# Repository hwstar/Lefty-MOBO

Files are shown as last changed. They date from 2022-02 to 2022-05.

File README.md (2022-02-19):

# Lefty-MOBO
Lefty Double Conversion Transceiver Motherboard

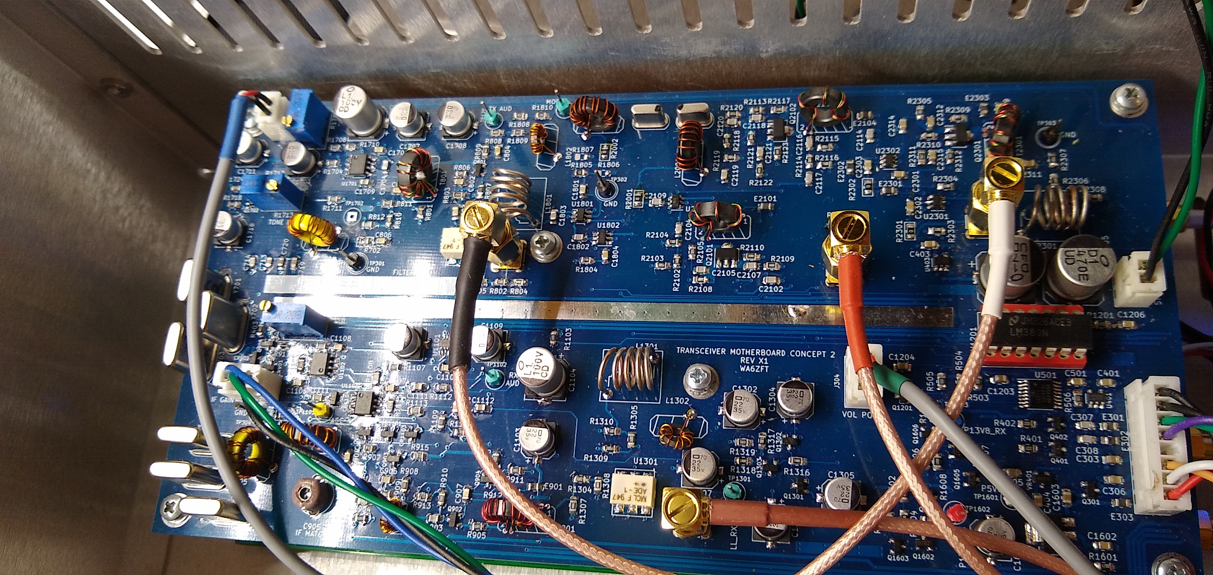
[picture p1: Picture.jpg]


This is an HF Motherboard consisting of the entire signal chain from RF in to Speaker, and from Microphone to RF out.  A double conversion topology was chosen to allow the motherboard to operate on all HF bands with minimal intermodulation products close to the operating frequency.

The design uses 5 AS169-73 Skyworks RF switches,  3 Mini Circuits ADE-1 mixers, a pair 45.1 MHz matched Golledge 15 KHz BW IF filters, 6 matched 12.288 MHz crystals for the second IF SSB filter, and 3 2SC3357 low noise RF transistors in the 45.1 MHz "transverter" section. The speaker amplifier is an LM380.

This design was inspired from W7ZOI's single conversion "Lichen" Transceiver originally published in EMRFD. I use the dual JFET IF amplifer, AGC circuit, 3 transistor post-detector audio amplifier, and TX speech amplifier from that design in this design.

Please note that this is not a complete Transceiver system. The transceiver board will additionally require a 3 output VFO (My implementation uses one SI5351, and may use 2 of them in the future so that I can drive all the Mixers at 8mA) ,  external bandpass filter bank, an RF power amplifier, and a TX low pass filter bank.

Mixer 1 (U801) serves as a downconverter in RX mode, and a balanced modulator TX mode. This converts the 45.1 MHz first IF to 12.288 MHz second IF. In TX mode, the VFO provides the carrier frequency (which depends on the characteristics of the crystal filter)

Mixer 2 (U1301) serves as the product detector in RX mode, and a 12.288 MHz upconverter in TX mode.

Mixer 3 (U2201) provides downconversion from the 45.1 MHz first IF to the desired HF band.

Mixer 1, The first IF amplifier, and Mixer 2 operate in the same direction for both TX and RX, but the mixers change function depending upon whether they're being used in TX or RX. A pair of AS169-73 RF switches, some RF chokes and RF traps are used to select the TX mode, and to filter out RF from getting into the audio stages.

The 45.1 MHz first IF uses the "BITx" concept with 2SC3357 bidirectional amplifiers i.e. left-to-right, and right-to-left controlled by a pair of AS169-73 RF switches, and the P13V8_RX and P13V8_TX power rails. The 2SC3357's are biased for 40mA operation.

After Mixer3 there is a stage of TX RF amplification using a 2SC3357 to bring up the signal level what is required for the RF power amplifier (not included on this board). This amplifier is bypassed in RX mode using a AS169-73.

All control to the Lefty Motherboard is done over I2C using an NXP PCA9554 at 7 bit address 0x38. This allows the wiring from the Motherboard to be minimal. 
The I2C interface allows control AS169-73 RF switches, PTT, Rx Audio Mute circuit, AGC on/off, and the TX tune audio oscillator. The SCL and SDA pins at the connector operate at 3.3V and are intended to be used with newer 3.3V microcontrollers available such as the STM32 "black pill".

There is an I2C EEPROM on the board to facilitate storing the TX gain values for each band, and crystal filter 6dB points and bandwidth, and a DAC which is used to control the 12.288 MHz IF amplifier's gain in TX to help flatten out the TX power across all bands. TX gain may also be set manually by removing the DAC and and installing a 20K pot at R918. 

The PCB design was done with KiCAD 5.0. The BOM files are in .csv format and are included in the top level directory. There is a combined BOM, separate top and bottom SMT BOM's, and a PTH BOM.

The gerber files are in the directory TRX_MB_C2_X1

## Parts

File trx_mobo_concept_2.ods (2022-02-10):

Item | Part Number | Qty | Reference(s) | Title/Description | Value on Schematic | Manufacturer | Manufacturer Part Number
1 | 800238-104 | 48 | C301,C302,C305,C309,C310,C401-C403,C501,C801-C806,C901,C902,C906-C910,C1101,C1105-C1108,C1201,C1206,C1303,C1602,C1701,C1705,C1706,C1710,C1801,C1802,C1804,C2301-C2304,C2309-C2312,C2314,C2315 | CAP,0805,0.1u,50V,X7R | 0.1u | Open Market | N/A
2 | 800267-226 | 14 | C1102,C1103,C1109,C1302,C1304-C1307,C1601,C1703,C1707,C1708,C1711,C1716 | CAP,ALUM ELECT,GP,22UF,25V,SMD,CS=6.3MM | 22u | Open Market | N/A
3 | 800268-107 | 2 | C1104,C1702 | CAP,ALUM,ELECT,GP,100UF,35V,SMD,CS=8MM | 100u | Open Market | N/A
4 | 800238-105 | 2 | C404,C1110 | CAP,0805,1u,50V,X7R | 1u | Open Market | N/A
5 | 800003-475 | 5 | C1111,C1112,C1203,C1204,C1603 | CAP,0805,4.7u,25V,X5R | 4.7u | Open Market | N/A
6 | 800270-477 | 2 | C1202,C1205 | CAP,ALUM,ELECT,GP,470UF,25V,SMD,CS=10MM | 470u | Open Market | N/A
7 | 800232-151 | 3 | C1301,C1805,C2313 | CAP,0805,C0G,150PF,250V | 150p | Open Market | N/A
8 | 800239-103 | 1 | C1704 | CAP,0805,C0G/NPO,10000PF,50V | 0.01u | Open Market | N/A
9 | 800239-272 | 5 | C1709,C1712-C1715 | CAP,0805,C0G/NPO,2700PF,50V | 0.0027u | Open Market | N/A
10 | 800238-103 | 21 | C903,C904,C1717,C1803,C2101-C2109,C2114-C2121 | CAP,0805,0.01u,50V,X7R | 0.01u | Open Market | N/A
11 | 800239-160 | 2 | C2001,C2003 | CAP,0805,C0G/NPO,16PF,50V | 16p | Open Market | N/A
12 | 800239-082 | 1 | C2002 | CAP,0805,C0G/NPO,8.2PF,50V | 8.2p | Open Market | N/A
13 | 800238-102 | 8 | C2110-C2113,C2305-C2308 | CAP,0805,1000p,50V,X7R | 1000p | Open Market | N/A
14 | 800003-106 | 3 | C303,C306,C405 | CAP,0805,10u,25V,X5R | 10u | Open Market | N/A
15 | 800239-102 | 1 | C304 | CAP,0805,C0G/NPO,1000PF,50V | 1000p | Open Market | N/A
16 | 800239-101 | 2 | C307,C308 | CAP,0805,C0G/NPO,100PF,50V | 100p | Open Market | N/A
17 | 800239-431 | 2 | C701,C702 | CAP,0805,C0G/NPO,430PF,50V | 430p | Open Market | N/A
18 | 800239-150 | 2 | C703,C704 | CAP,0805,C0G/NPO,15PF,50V | 15p | Open Market | N/A
19 | 800239-121 | 2 | C705,C710 | CAP,0805,C0G/NPO,120PF,50V | 120p | Open Market | N/A
20 | 800239-151 | 7 | C706,C709,C712,C713,C716,C717,C719 | CAP,0805,C0G/NPO,150PF,50V | 150p | Open Market | N/A
21 | 800239-100 | 4 | C707,C708,C714,C715 | CAP,0805,C0G/NPO,10PF,50V | 10p | Open Market | N/A
22 | 800239-180 | 1 | C711 | CAP,0805,C0G/NPO,18PF,50V | 18p | Open Market | N/A
23 | 800239-200 | 2 | C718,C720 | CAP,0805,C0G/NPO,20PF,50V | 20p | Open Market | N/A
24 | 800241-600 | 1 | C905 | CAP,TRIMMER,PLASTIC,PTH,6MM,60PF | 60p | Open Market | N/A
25 | 800127-101 | 6 | CR901,CR902,CR1101-CR1104 | DIODE,SCHOTTKY,SGL,SOT-23 | BAT54 | Diodes Inc. | BAT54-7-F
26 | 800245-601 | 11 | E301-E303,E901,E2101-E2104,E2301-E2303 | FERRITE,CHIP,0805,600 ohm,100MHz,500mA | GZ2012U601TF | Sunlord | GZ2012U601TF
27 | 800253-101 | 4 | J301,J303,J305,J308 | CONN, SMA, VERTICAL, PCB MOUNT | CONN_SMA_VERT | Kinghelm | KH-SMA-KE-Z
28 | 800114-102 | 2 | J302,J307 | CONN,HDR,SHROUDED,2 CKT,5MM,XH SERIES | CONN2 | JST | B2B-XH-A
29 | 800114-103 | 2 | J304,J306 | CONN,HDR,SHROUDED,3 CKT,5MM,XH SERIES | CONN3 | JST | B3B-XH-A
30 | 800114-108 | 1 | J309 | CONN,HDR,SHROUDED,8 CKT,5MM,XH SERIES | CONN8 | JST | B8B-XH-A
31 | 800YYY-YYY | 3 | L1301,L1801,L2301 | Unknown | 81nH | Unknown | Unknown
32 | 800257-023 | 3 | L901,L1302,L1802 | FERRITE,TOROID,OD 5.95MM,TYPE 43 | 27uH | Open Market | FT23-43
33 | 800234-370 | 2 | L2001,L2002 | TOROID,POWDERED_IRON,T37-10 | 0.563uH | Open Market | N/A
34 | 800234-376 | 2 | L701,L702 | TOROID,POWDERED_IRON,T37-6 | 0.97uH | Open Market | N/A
35 | 800276-037 | 1 | L902 | FERRITE,TOROID,OD 9.5MM,TYPE 61 | 4.13uH | Open Market | FT37-61
36 | 800236-101 | 7 | Q301,Q401,Q402,Q905,Q1201,Q1602,Q1605 | XSTR,SOT-23,MOSFET,N-CH,50V | BSS138 | Open Market | BSS138
37 | 800259-101 | 10 | Q801,Q903,Q904,Q1301-Q1303,Q1603,Q1606,Q1702,Q1703 | XSTR,GP,NPN,SOT-23,FT=300MHz | MMBT3904 | Open Market | MMBT3904
38 | 800134-101 | 2 | Q1601,Q1604 | XSTR,MOSFET,P-CH,SOT-23,30V,-7.6A | SI2369 | Vishay | SI2369DS-T1-E3
39 | 800275-101 | 1 | Q1701 | XSTR,PNP,GP,FT=300MHZ,SOT-23 | MMBT3906 | Open Market | MMBT3906
40 | 800246-101 | 3 | Q2101,Q2102,Q2301 | XSTR,BJT,NPN,RF,SOT89,1.2W | 2SC3357 | Open Market | 2SC3357
41 | 800263-101 | 2 | Q901,Q902 | XSTR,RF,J-FET,N-CH,DEPLETION MODE | MMBFJ310 | Open Market | MMBFJ310
42 | 800235-103 | 25 | R301,R401,R402,R501,R502,R915,R916,R1101,R1102,R1106,R1107,R1110,R1111,R1113,R1315,R1602,R1605,R1606,R1609,R1702-R1704,R1706,R1707,R1724 | RES,0805,10K,1% | 10K | Open Market | N/A
43 | 800235-101 | 7 | R403,R1103,R1318,R1604,R1608,R1701,R1718 | RES,0805,100,1% | 100 | Open Market | N/A
44 | 800235-104 | 3 | R1104,R1108,R1711 | RES,0805,100K,1% | 100K | Open Market | N/A
45 | 800235-225 | 1 | R1105 | RES,0805,2.2M,1% | 2.2M | Open Market | N/A
46 | 800235-102 | 10 | R503-R506,R1109,R1312,R1314,R1712,R1808,R1810 | RES,0805,1.0K,1% | 1K | Open Market | N/A
47 | 800235-471 | 2 | R1112,R1601 | RES,0805,470,1% | 470 | Open Market | N/A
48 | 800235-473 | 9 | R1114,R1311,R1714,R1717,R1719-R1722,R1725 | RES,0805,47K,1% | 47K | Open Market | N/A
49 | 800235-027 | 1 | R1201 | RES,0805,2.7,1% | 2.7 | Open Market | N/A
50 | 800235-180 | 6 | R802,R1301,R1304,R1801,R1805,R2201 | RES,0805,18,1% | 18 | Open Market | N/A
51 | 800235-301 | 8 | R804,R805,R1302,R1303,R1307,R1308,R2202,R2203 | RES,0805,300,1% | 300 | Open Market | N/A
52 | 800235-360 | 6 | R810,R1305,R2102,R2114,R2118,R2306 | RES,0805,36,1% | 36 | Open Market | N/A
53 | 800235-000 | 10 | R701,R702,R917,R1306,R2001,R2002,R2106,R2107,R2301,R2302 | RES,0805,0,1% | 0 | Open Market | N/A
54 | 800235-151 | 12 | R811,R812,R1309,R1310,R2103,R2104,R2115,R2116,R2119,R2120,R2307,R2308 | RES,0805,150,1% | 150 | Open Market | N/A
55 | 800235-332 | 2 | R1313,R1317 | RES,0805,3.3K,1% | 3.3K | Open Market | N/A
56 | 800235-682 | 1 | R1316 | RES,0805,6.8K,1% | 6.8K | Open Market | N/A
57 | 800235-472 | 1 | R1319 | RES,0805,4.7K,1% | 4.7K | Open Market | N/A
58 | 800235-100 | 3 | R801,R1603,R1607 | RES,0805,10,1% | 10 | Open Market | N/A
59 | 800249-203 | 3 | R918,R1705,R1713 | RES,TRIMMER,3296,VERT,20K,10%,0.5W | 20K | Open Market | N/A
60 | 800235-681 | 1 | R1708 | RES,0805,680,1% | 680 | Open Market | N/A
61 | 800235-202 | 4 | R1709,R2101,R2113,R2305 | RES,0805,2.0K,1% | 2K | Open Market | N/A
62 | 800235-274 | 3 | R913,R914,R1710 | RES,0805,270K,1% | 270K | Open Market | N/A
63 | 800235-753 | 1 | R1715 | RES,0805,75K,1% | 75K | Open Market | N/A
64 | 800235-223 | 1 | R1716 | RES,0805,22K,1% | 22K | Open Market | N/A
65 | 800235-393 | 5 | R907,R908,R910,R911,R1723 | RES,0805,39K,1% | 39K | Open Market | N/A
66 | 800XXX-XXX | 4 | R1802,R1803,R1806,R1807 | Unknown | DNI | Unknown | Unknown
67 | 800235-510 | 2 | R1804,R1809 | RES,0805,51,1% | 51 | Open Market | N/A
68 | 800235-162 | 4 | R806,R2105,R2117,R2309 | RES,0805,1.6K,1% | 1.6K | Open Market | N/A
69 | 800235-361 | 3 | R2108,R2121,R2310 | RES,0805,360,1% | 360 | Open Market | N/A
70 | 800235-068 | 4 | R808,R2109,R2122,R2311 | RES,0805,6.8,1% | 6.8 | Open Market | N/A
71 | 800235-300 | 4 | R809,R2110,R2123,R2312 | RES,0805,30,1% | 30 | Open Market | N/A
72 | 800235-330 | 4 | R2111,R2112,R2303,R2304 | RES,0805,33,1% | 33 | Open Market | N/A
73 | 800235-392 | 1 | R803 | RES,0805,3.9K,1% | 3.9K | Open Market | N/A
74 | 800235-751 | 1 | R807 | RES,0805,750,1% | 750 | Open Market | N/A
75 | 800235-820 | 4 | R901,R902,R904,R905 | RES,0805,82,1% | 82 | Open Market | N/A
76 | 800235-222 | 2 | R903,R906 | RES,0805,2.2K,1% | 2.2K | Open Market | N/A
77 | 800235-391 | 2 | R909,R912 | RES,0805,390,1% | 390 | Open Market | N/A
78 | 800257-037 | 5 | T801,T901,T2101,T2102,T2301 | FERRITE,TOROID,OD 9.5MM,TYPE 43 | FT37-43 | Open Market | FT37-43
79 | 800207-101 | 13 | TP301-TP304,TP1101,TP1102,TP1301,TP1601-TP1603,TP1701,TP1702,TP1801 | TEST POINT, SGL,0.025 IN., SQ, PTH | TESTPINTPSQ025 | Open Market | N/A
80 | 800271-101 | 1 | U1101 | IC,SWITCH,ANALOG,HV,SPDT,SOT23-8 | DG449DS-T1-E3 | Vishay | DG449DS-E1-T3
81 | 800272-101 | 3 | U1102,U1103,U1701 | IC,OP-AMP,DUAL,RRIO,1.3MHZ,GBW,SOIC8 | LMC6482 | Texas Instruments | LMC6482AIM/NOPB
82 | 800269-101 | 1 | U1201 | IC,AUDIO AMPLIFIER,2.5W,DIP14 | LM380N | Texas Instruments | LM380N/NOPB
83 | 800262-101 | 3 | U801,U1301,U2201 | MODULE,MIXER,SMD,LEVEL 7,0.5 TO 500 MHZ | ADE-1 | Mini Circuits | ADE-1
84 | 800261-101 | 6 | U1801,U1802,U2101,U2102,U2301,U2302 | IC,RF SWITCH,SPDT,50 OHM | AS169-73 | Skyworks | AS169-73
85 | 800284-101 | 1 | U401 | IC,EEPROM,64KBIT,I2C,1.6-5.5V,SOT23-5 | 24CW640 | Microchip | 24CW640T-I/OT
86 | 800285-101 | 1 | U402 | IC,DAC,12 BIT,I2C,2.7-5.5V,SOT23-6 | MCP4725 | Microchip | MCP4725A1T-E/CH
87 | 800278-102 | 1 | U403 | IC,NAND GATE,2 INPUT,LVC,SOT23 | 74LVC1G00 | Texas Instruments | SN74LVC1G00DBVRG4
88 | 800237-101 | 1 | U501 | IC, I2C BUS EXPANDER, 8 BIT, TSSOP16 | PCA9554APW | NEXPERIA | PCA9554APW
89 | 800121-102 | 1 | VR1601 | IC,VREG,5V,1A,SOT-223 | NCP1117-5.0_SOT223 | On Semiconductor | NCP1117ST50
90 | 800187-101 | 1 | VR401 | IC,VREG,LDO,500MA,3.3V,SOT23 | ME6211A33M3G-N | Nanjing Micro One Elec | ME6211A33M3B-N
91 | 800287-101 | 2 | Y2001,Y2002 | FILTER,XTAL,MONOLITHIC,45.1 MHZ,15KHZ BW | 45.1 MHz | GOLLEDGE | GMCF-45T152AF
92 | 800286-101 | 6 | Y701-Y706 | CRYSTAL,HC-49U,12.288 MHZ,32PF | 12.288 MHz | CTS Crystals | MP122-E

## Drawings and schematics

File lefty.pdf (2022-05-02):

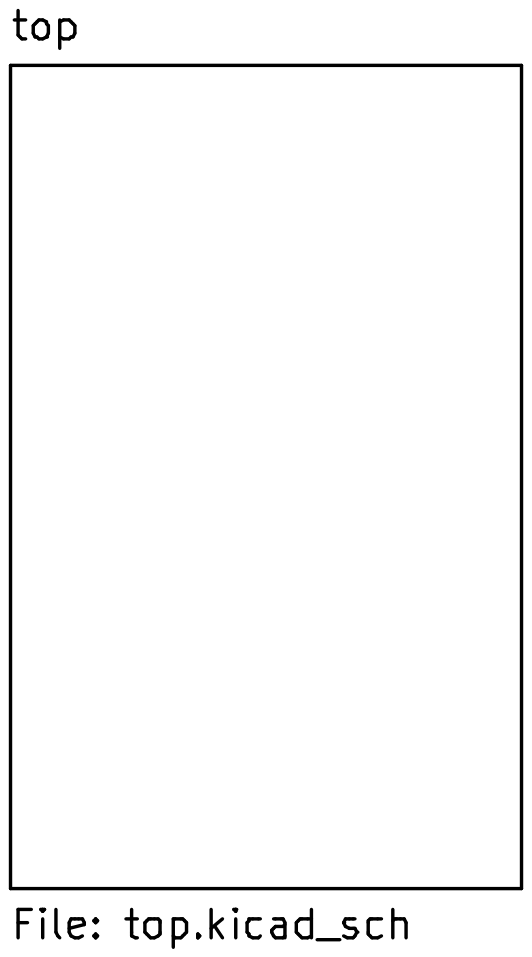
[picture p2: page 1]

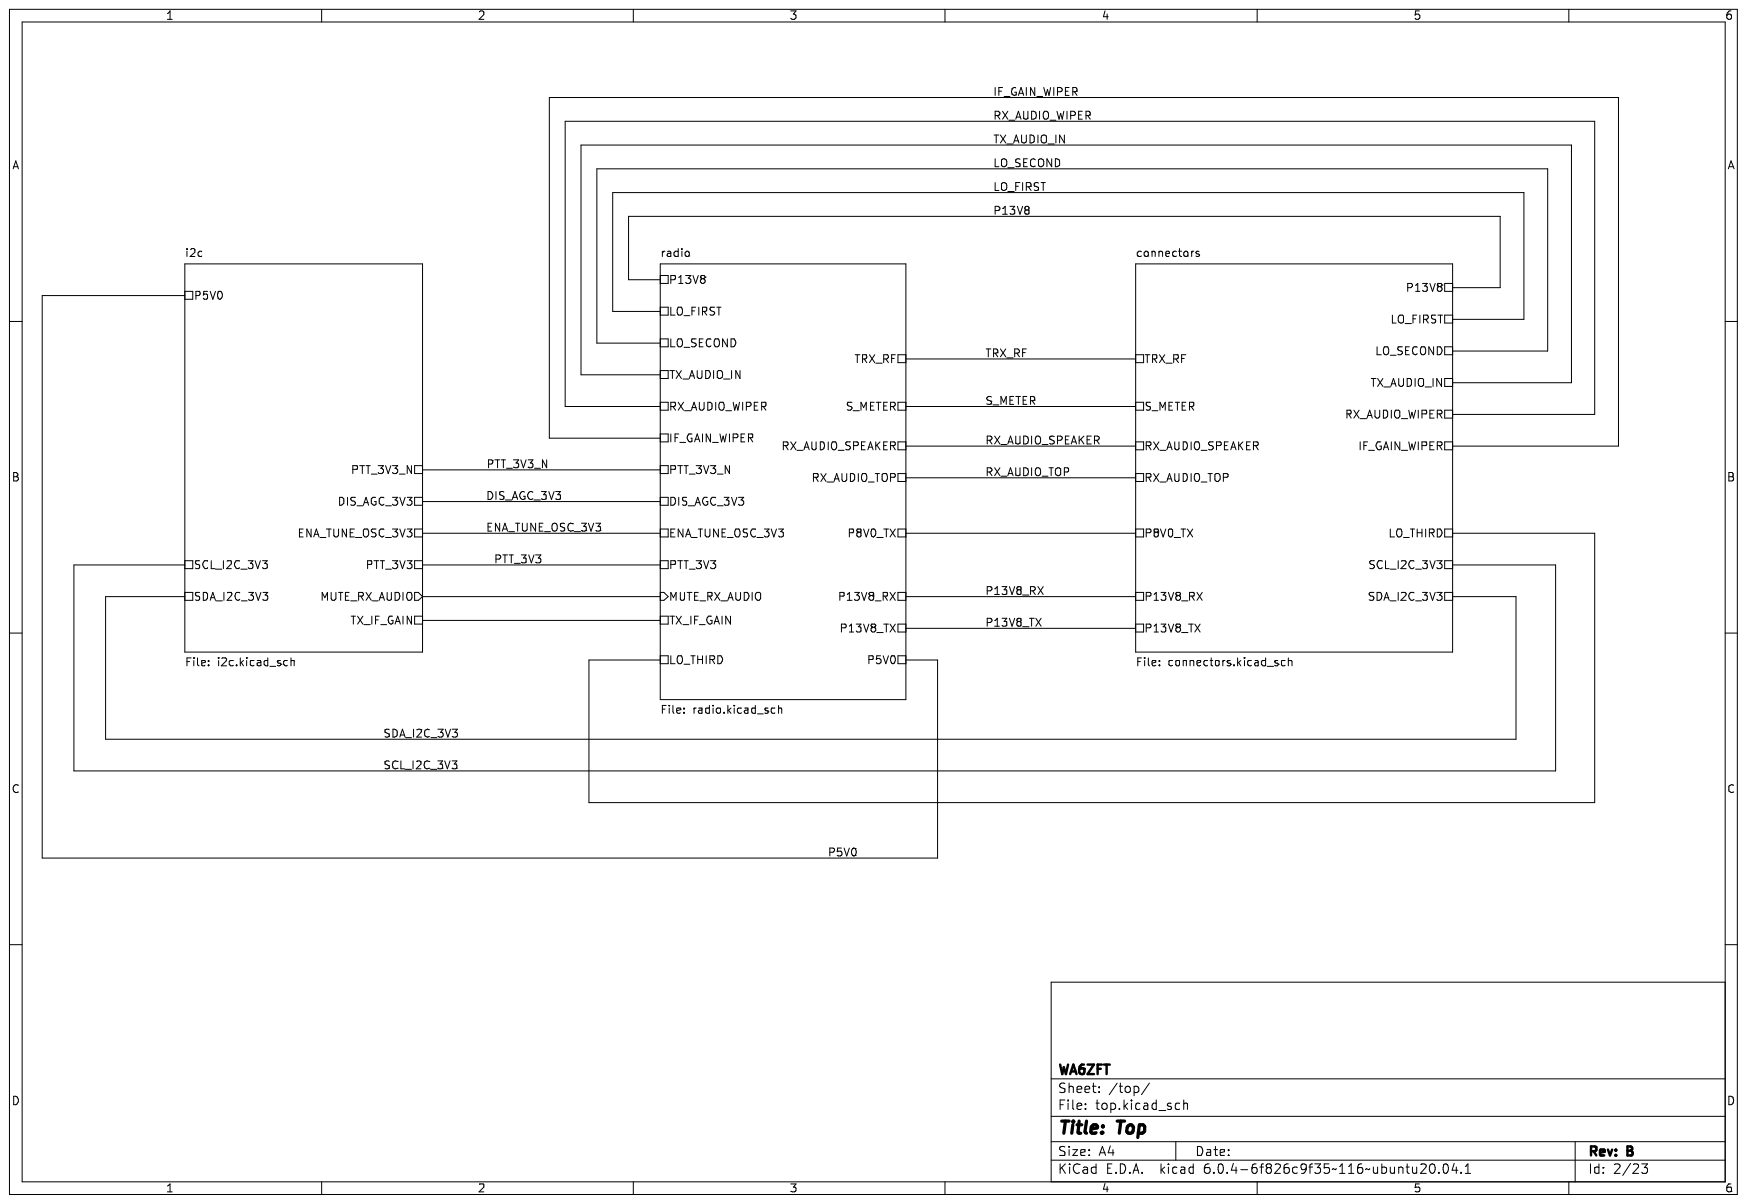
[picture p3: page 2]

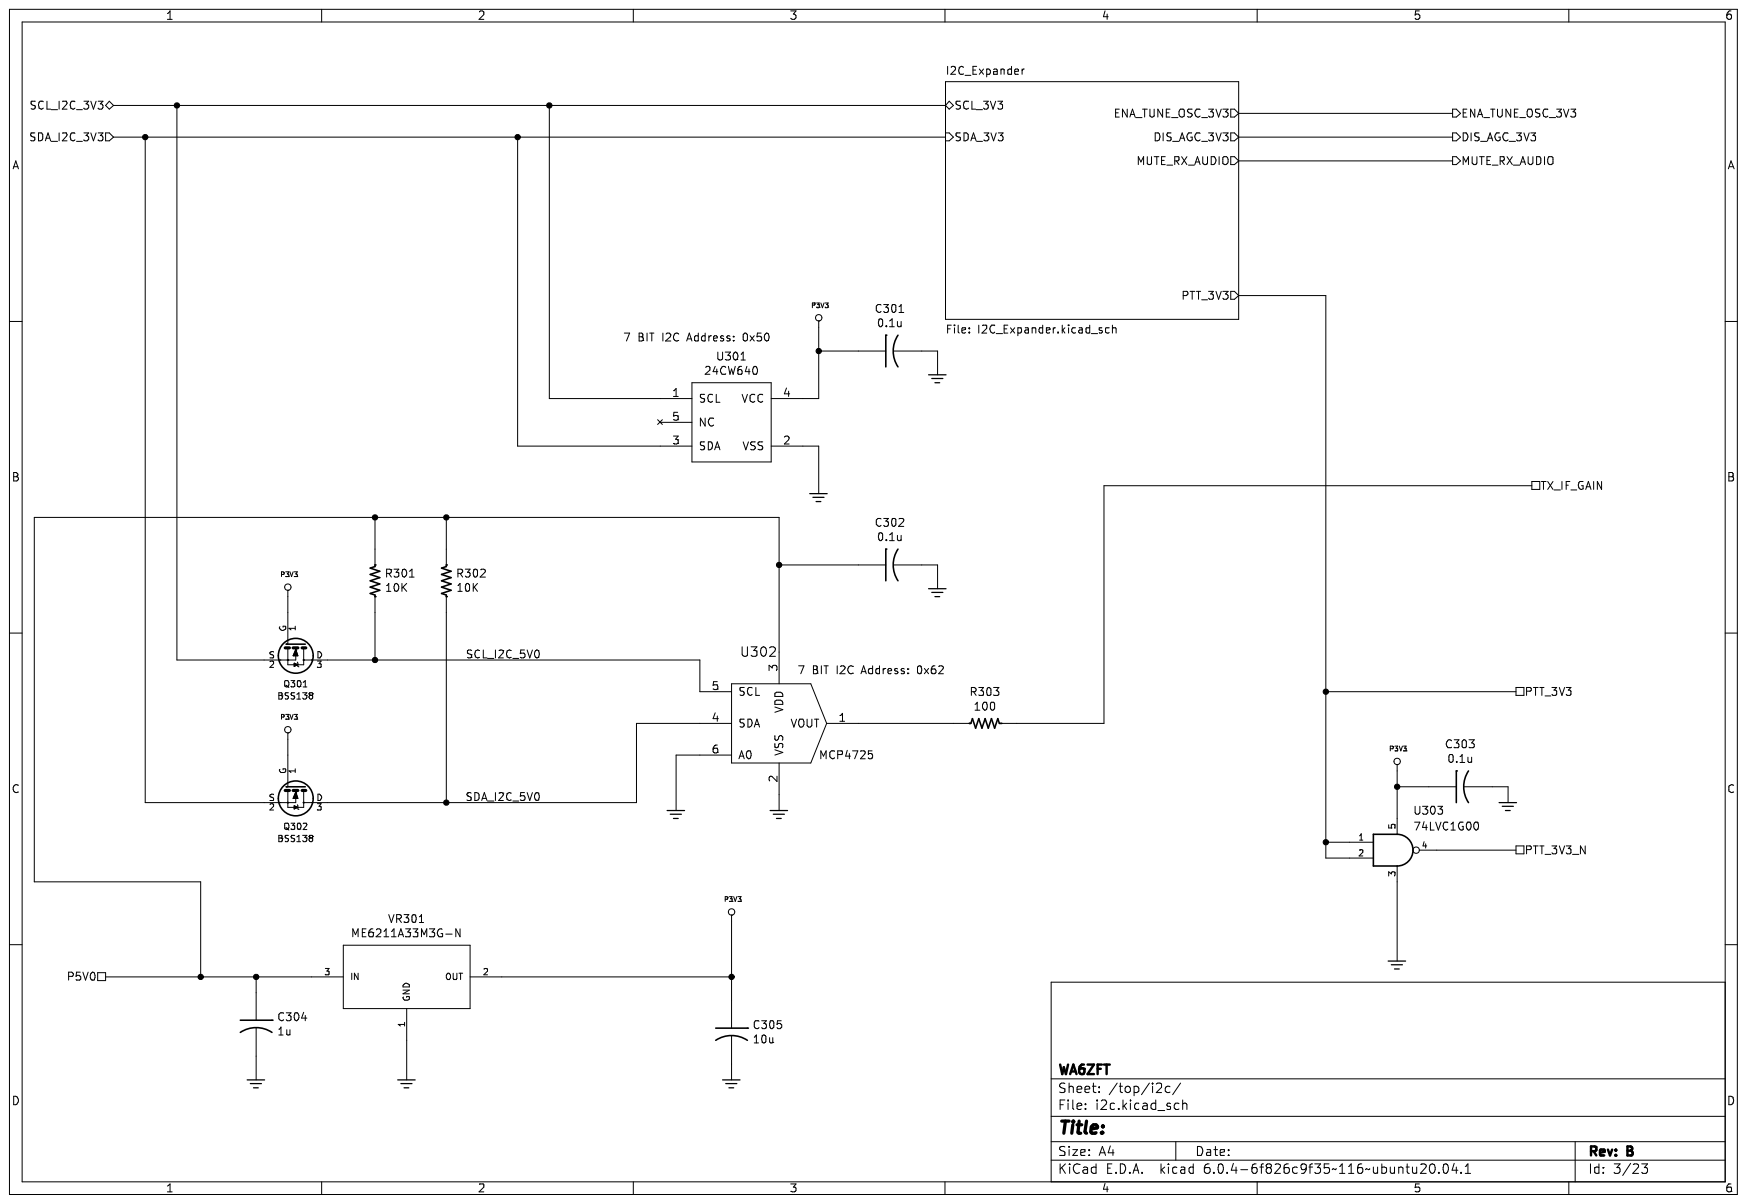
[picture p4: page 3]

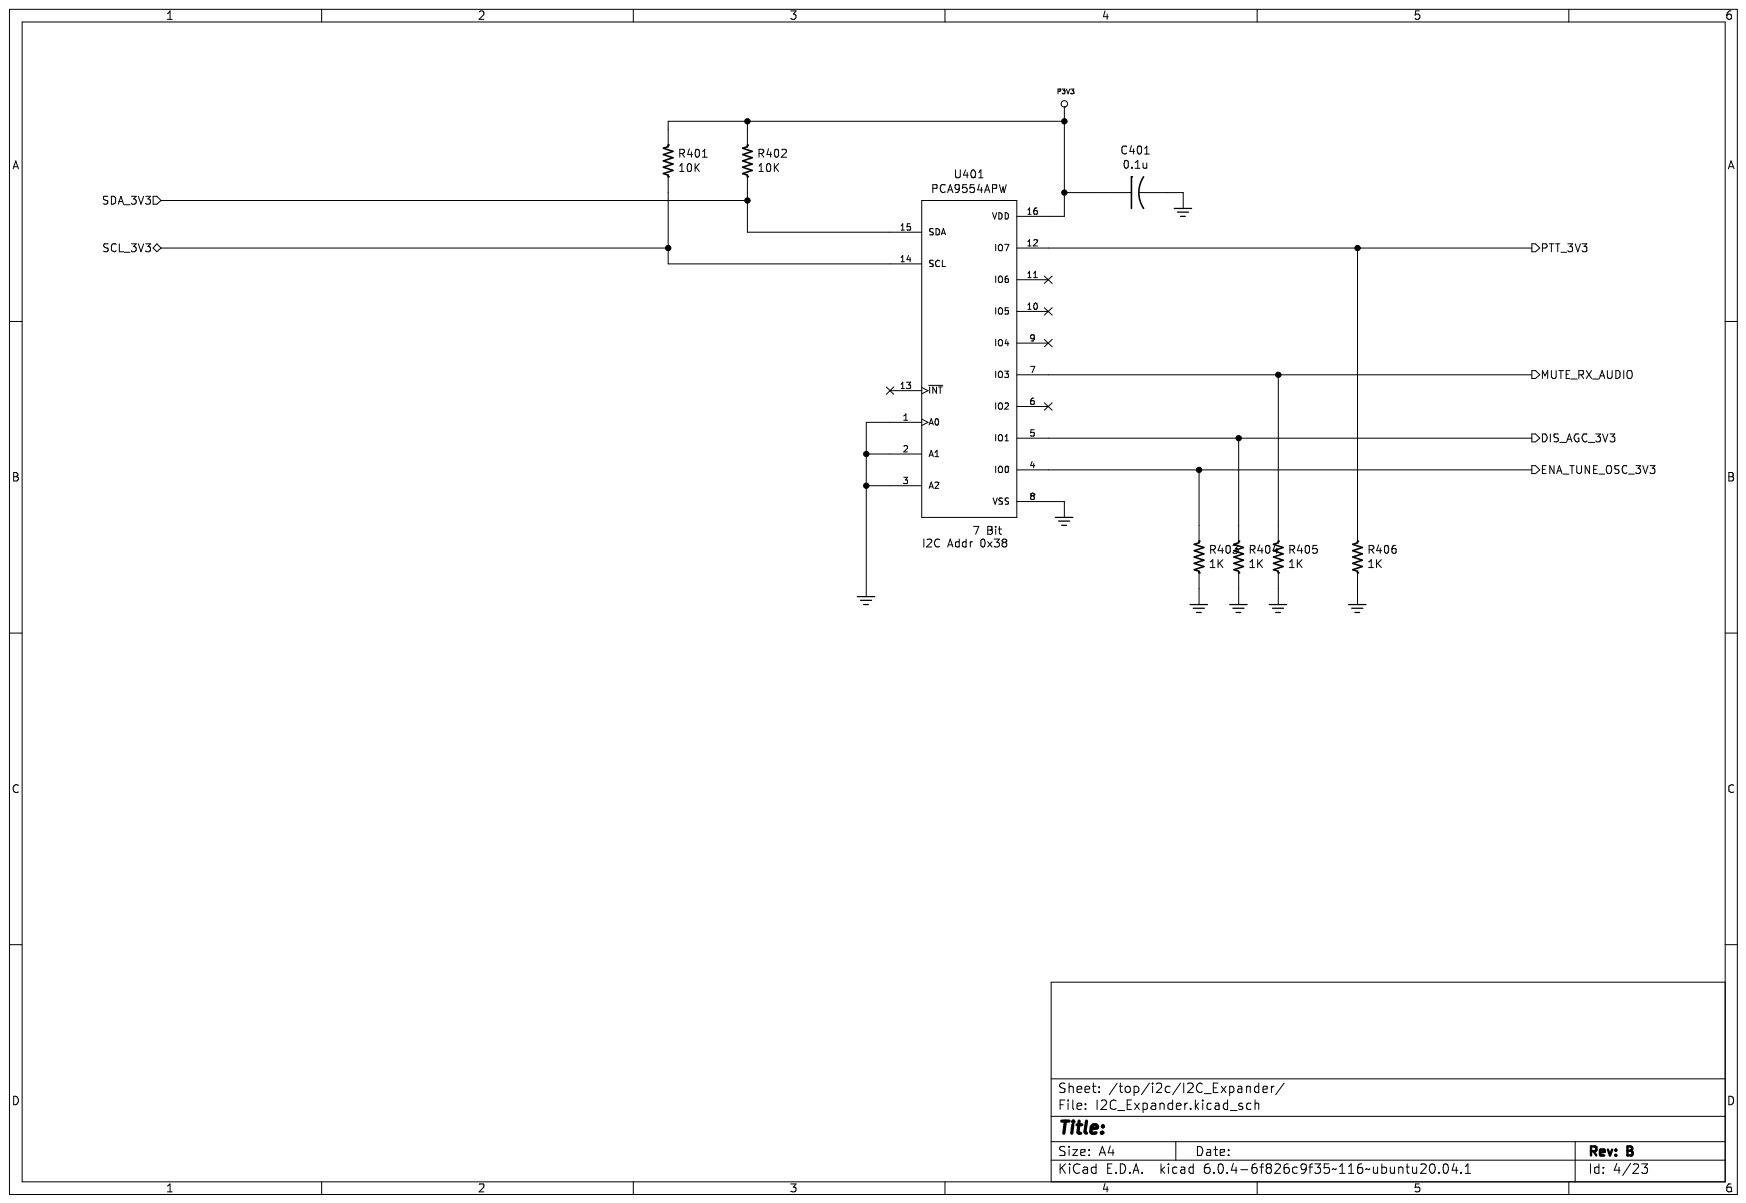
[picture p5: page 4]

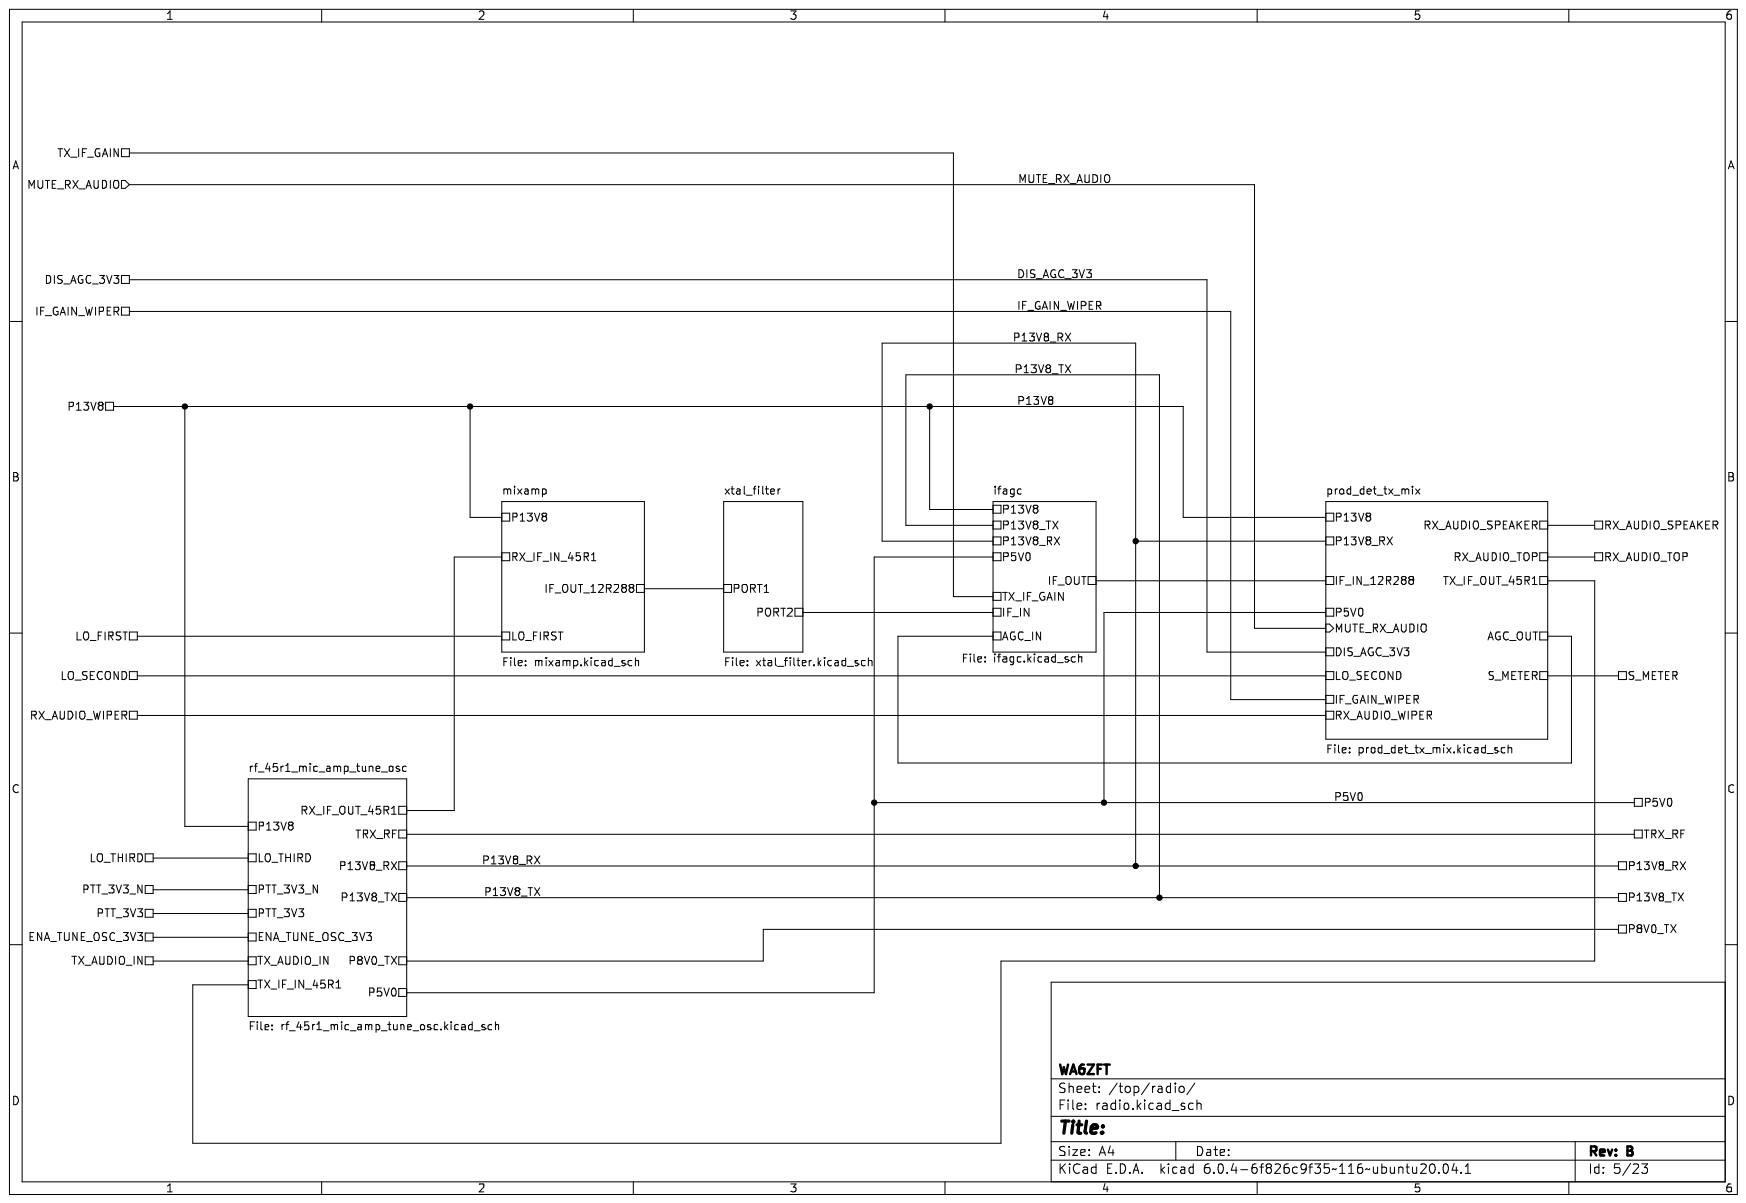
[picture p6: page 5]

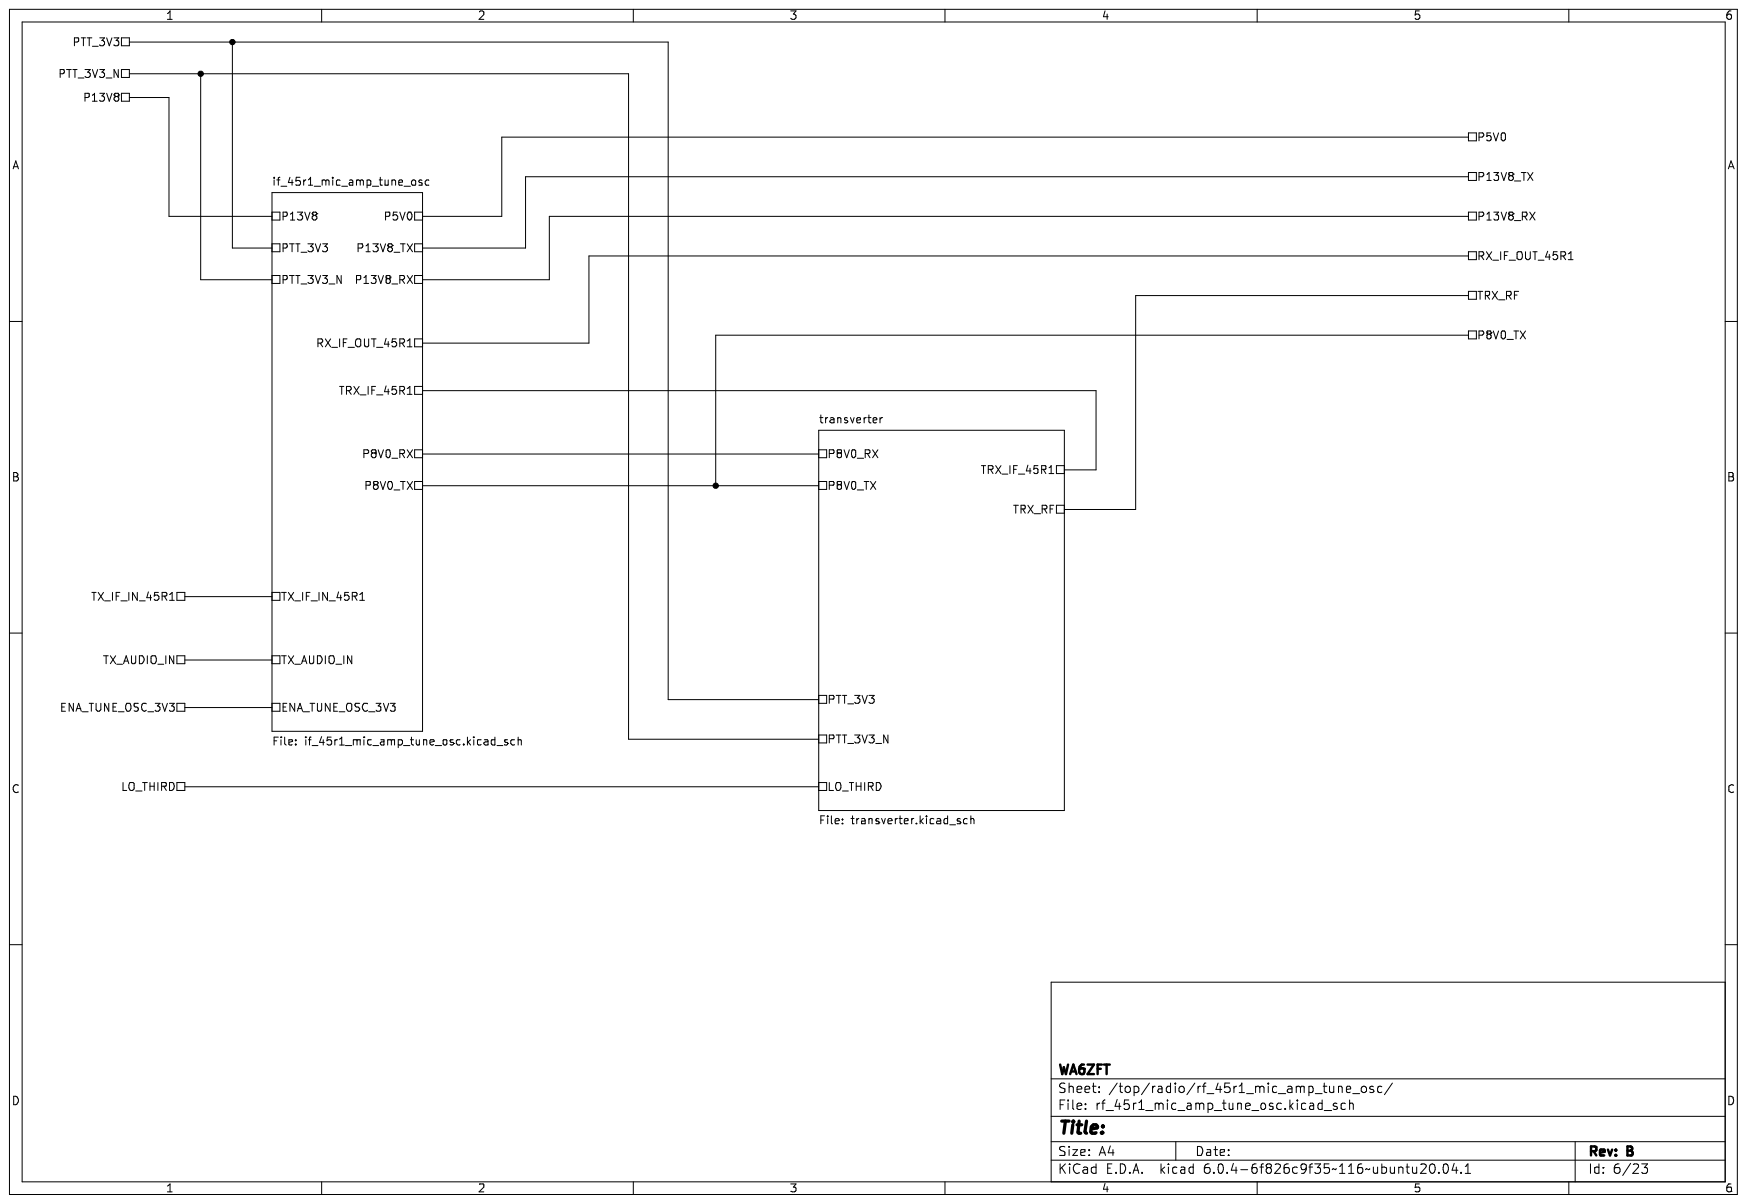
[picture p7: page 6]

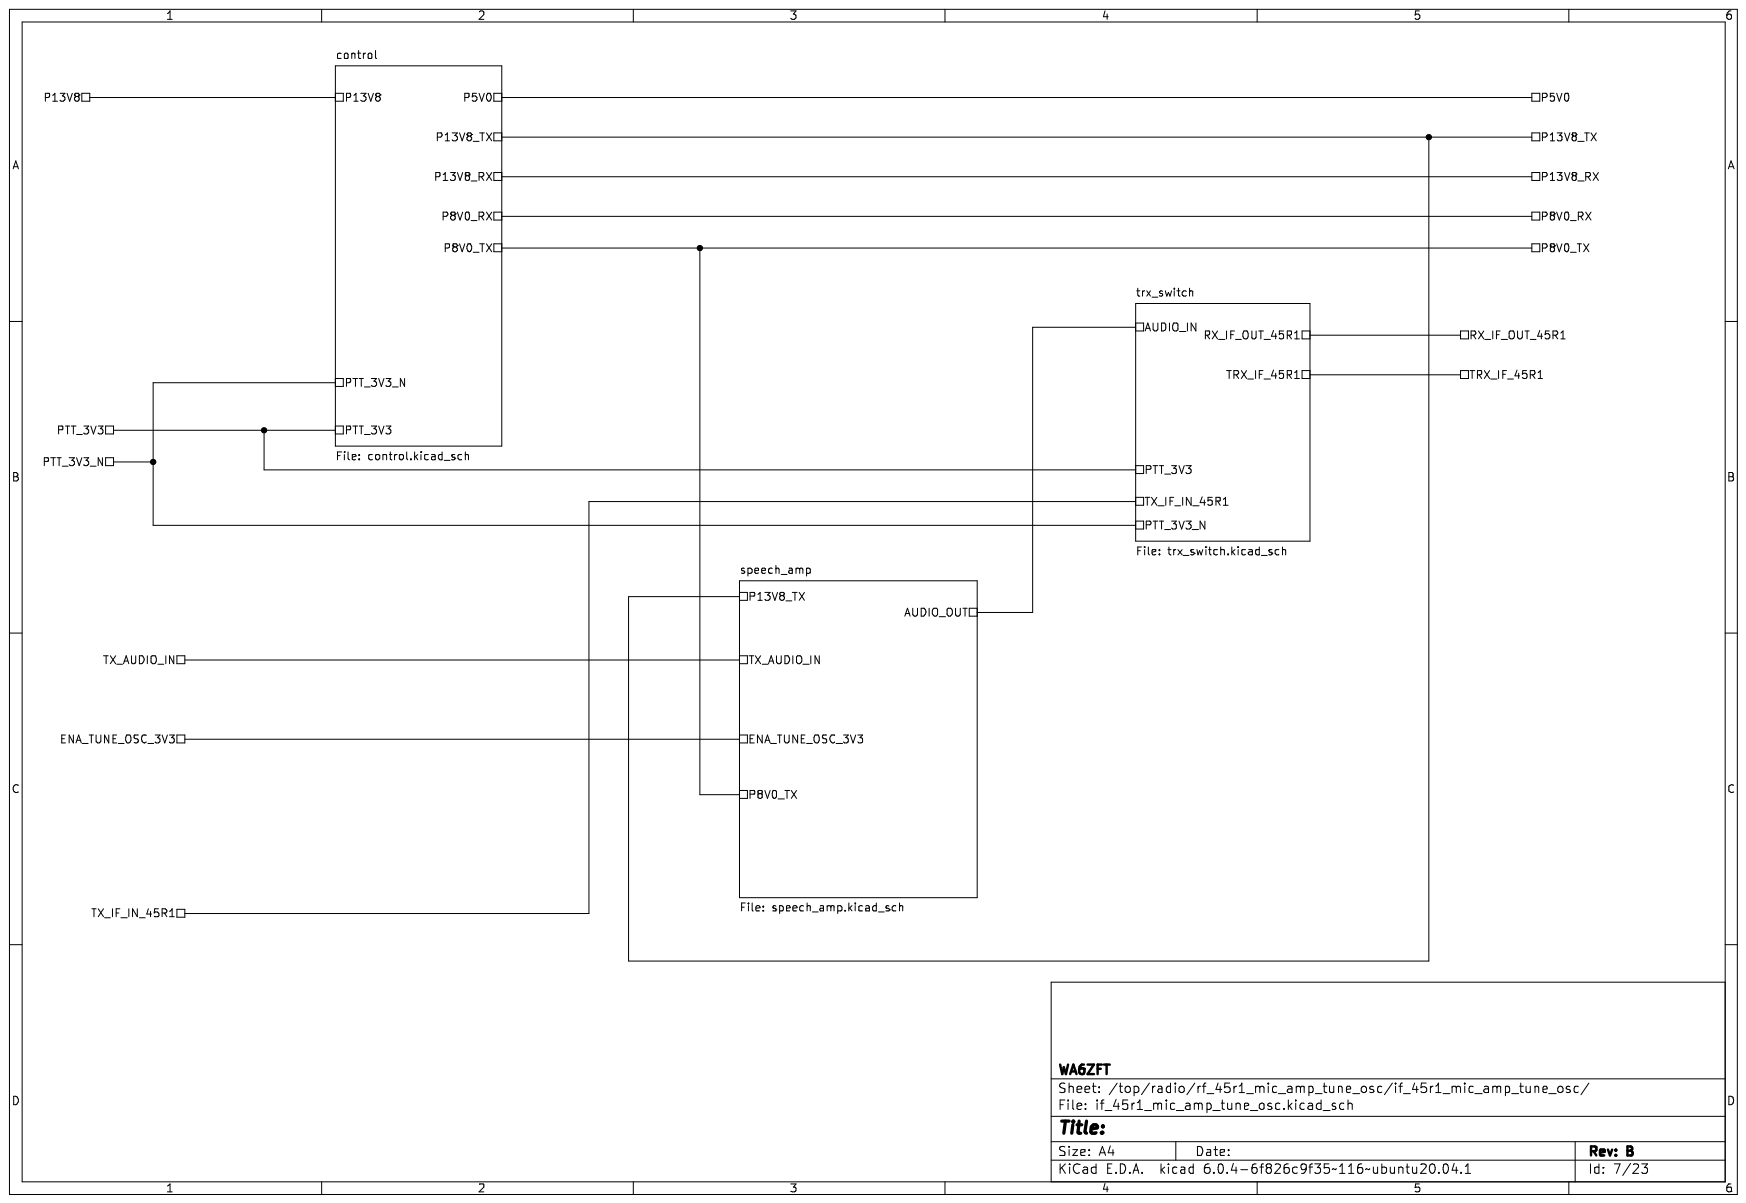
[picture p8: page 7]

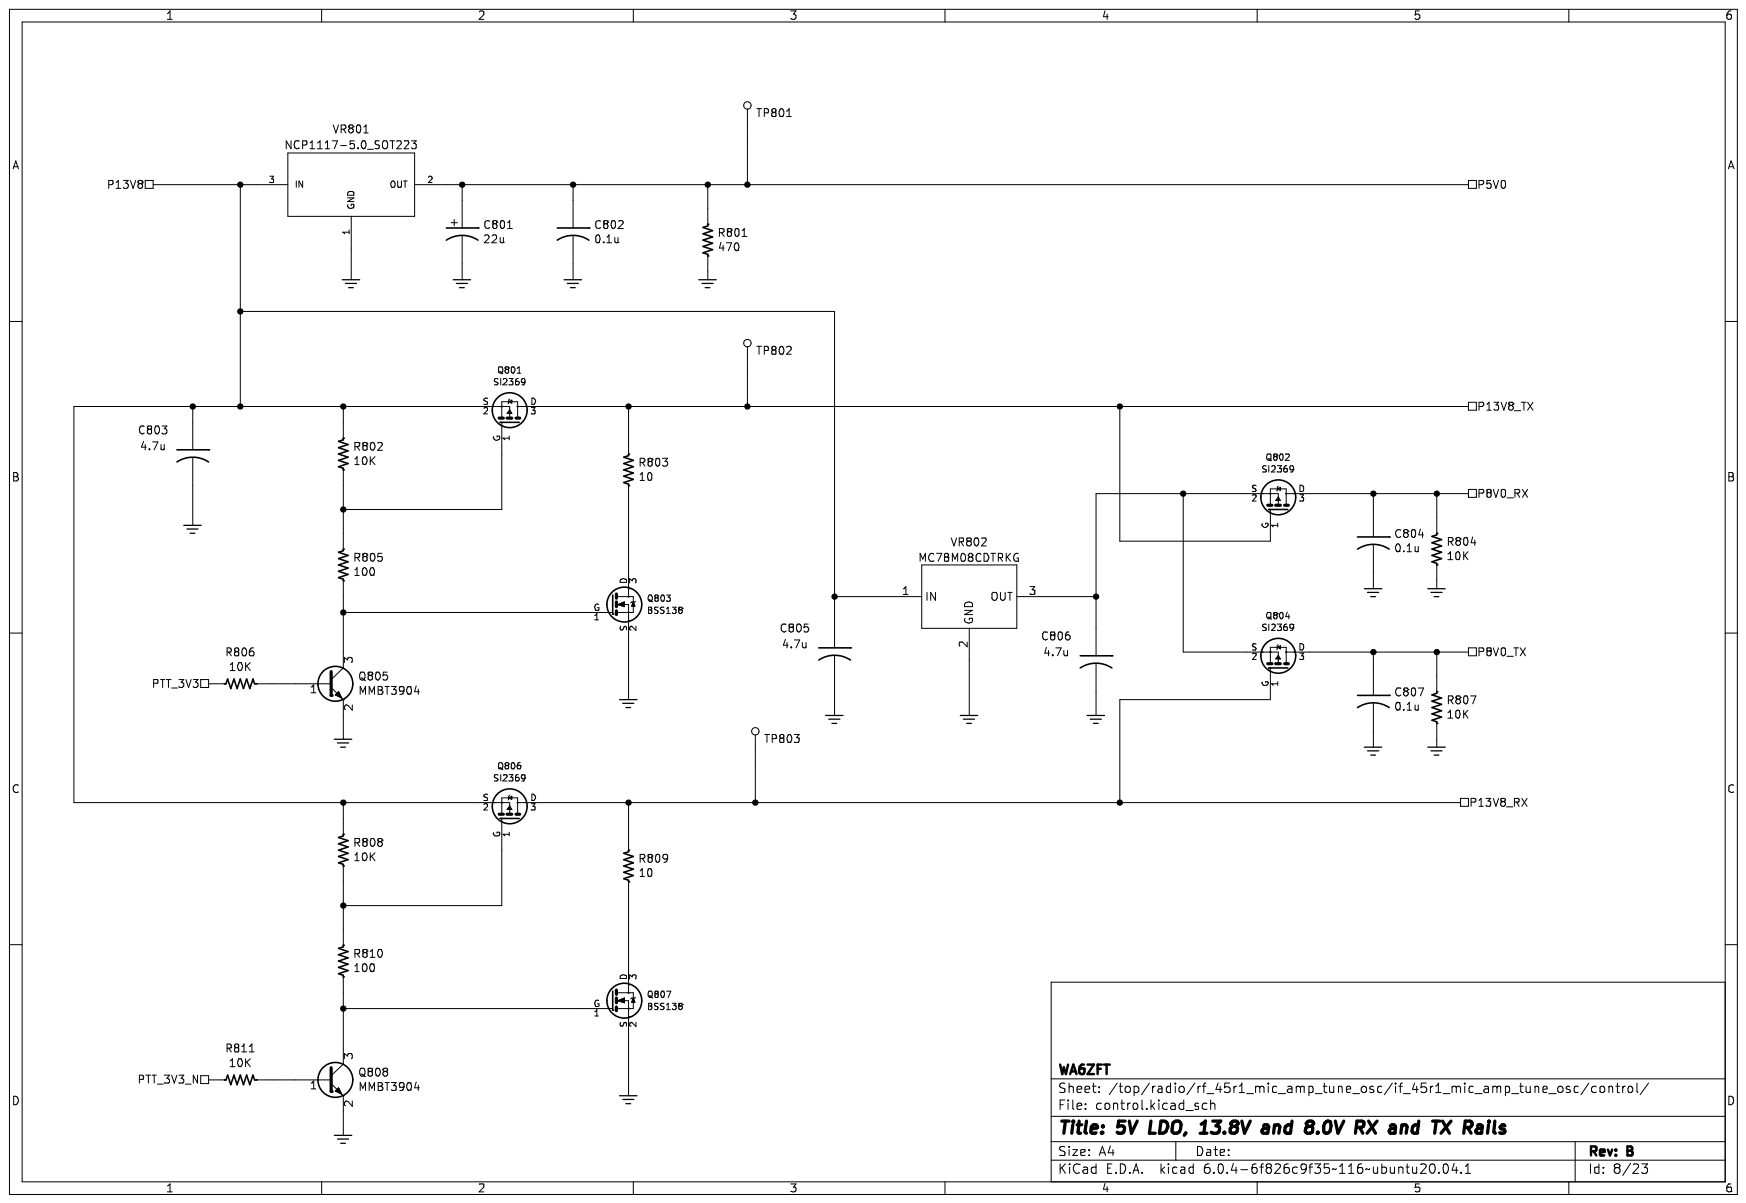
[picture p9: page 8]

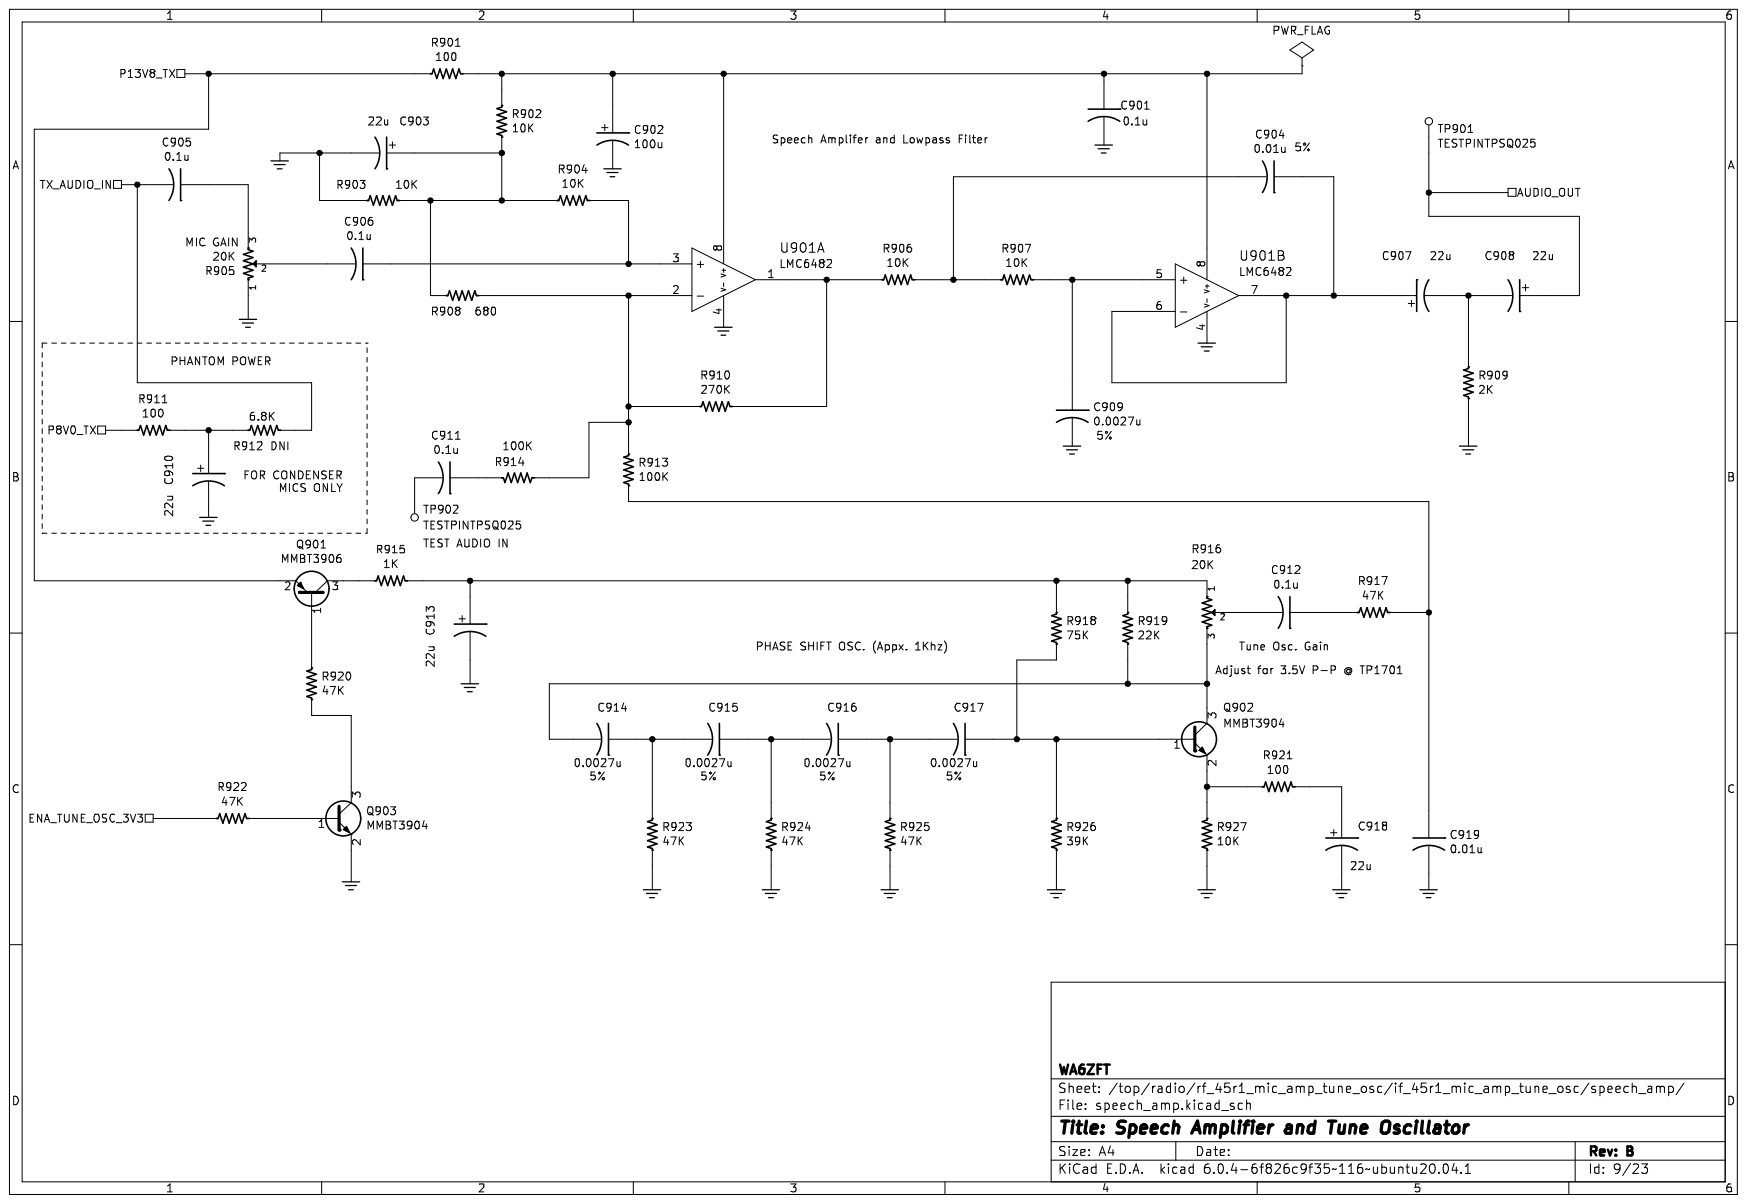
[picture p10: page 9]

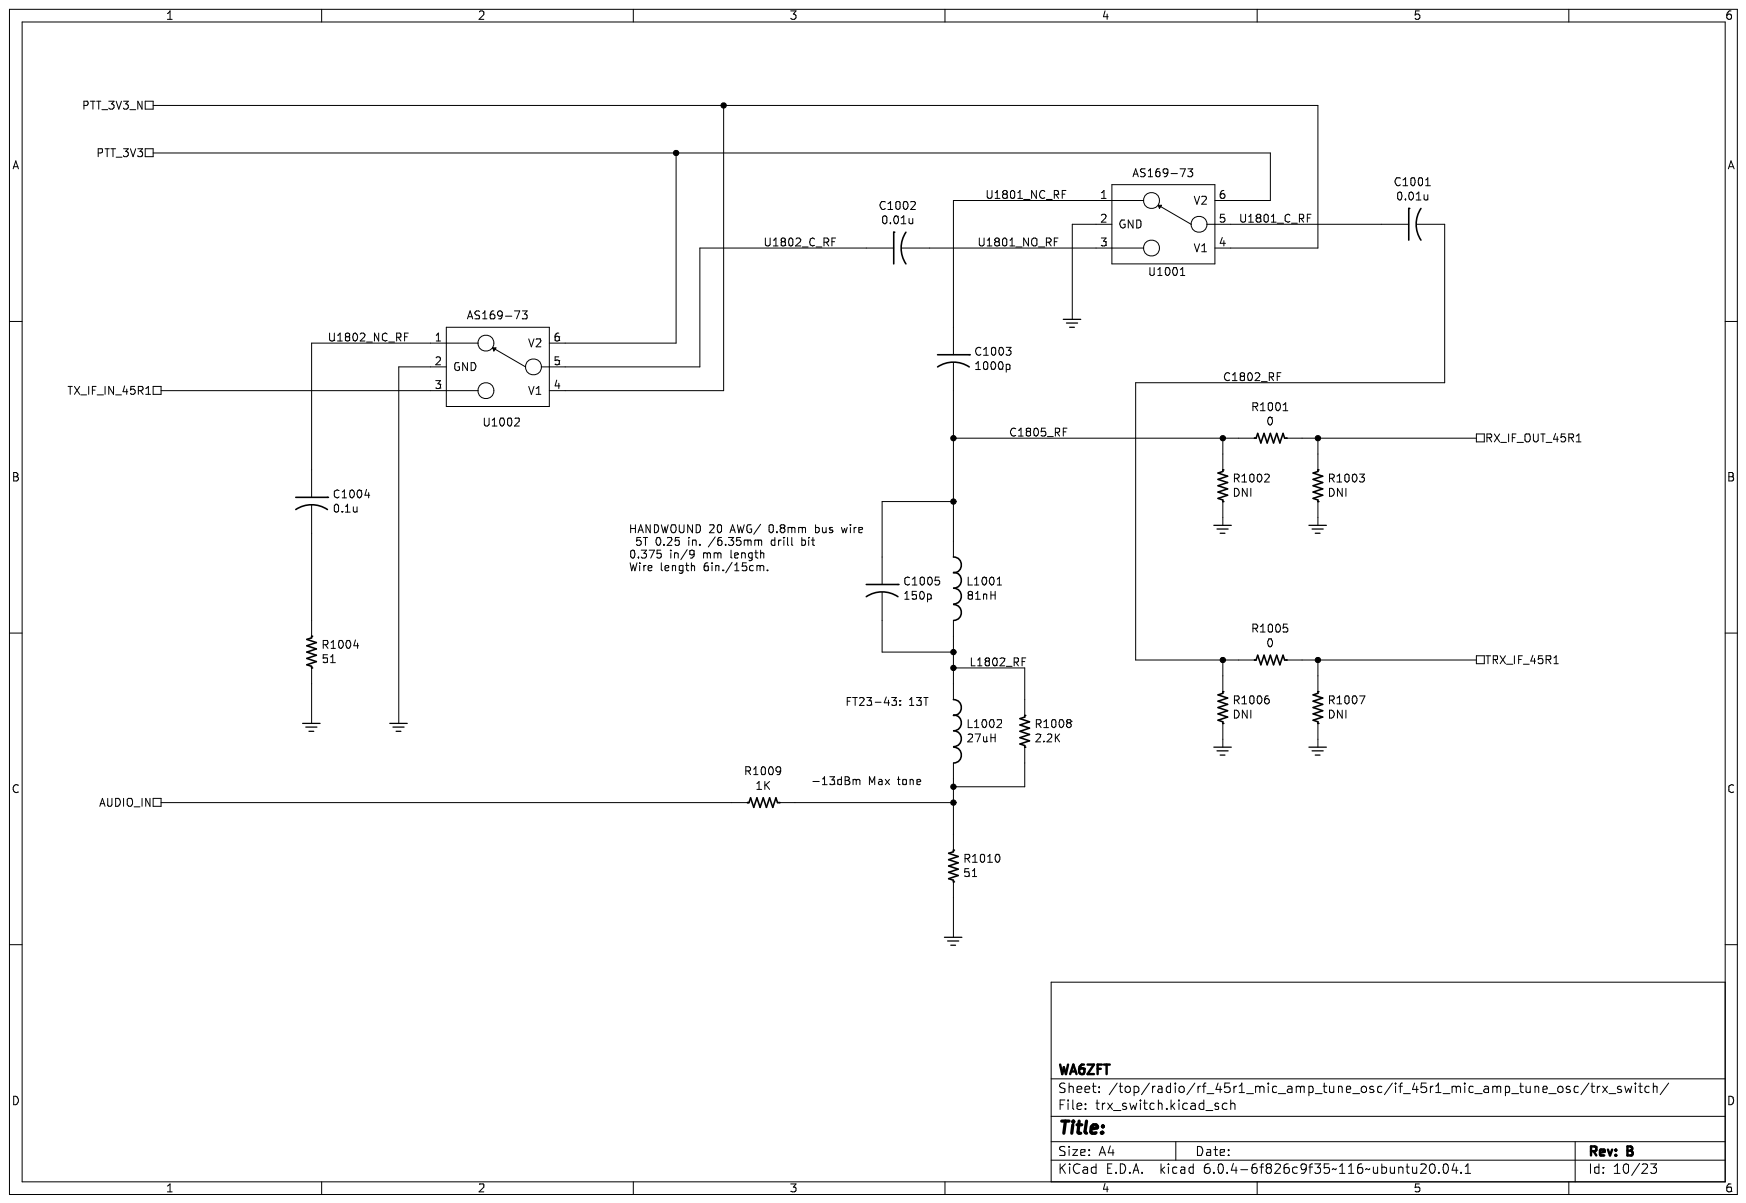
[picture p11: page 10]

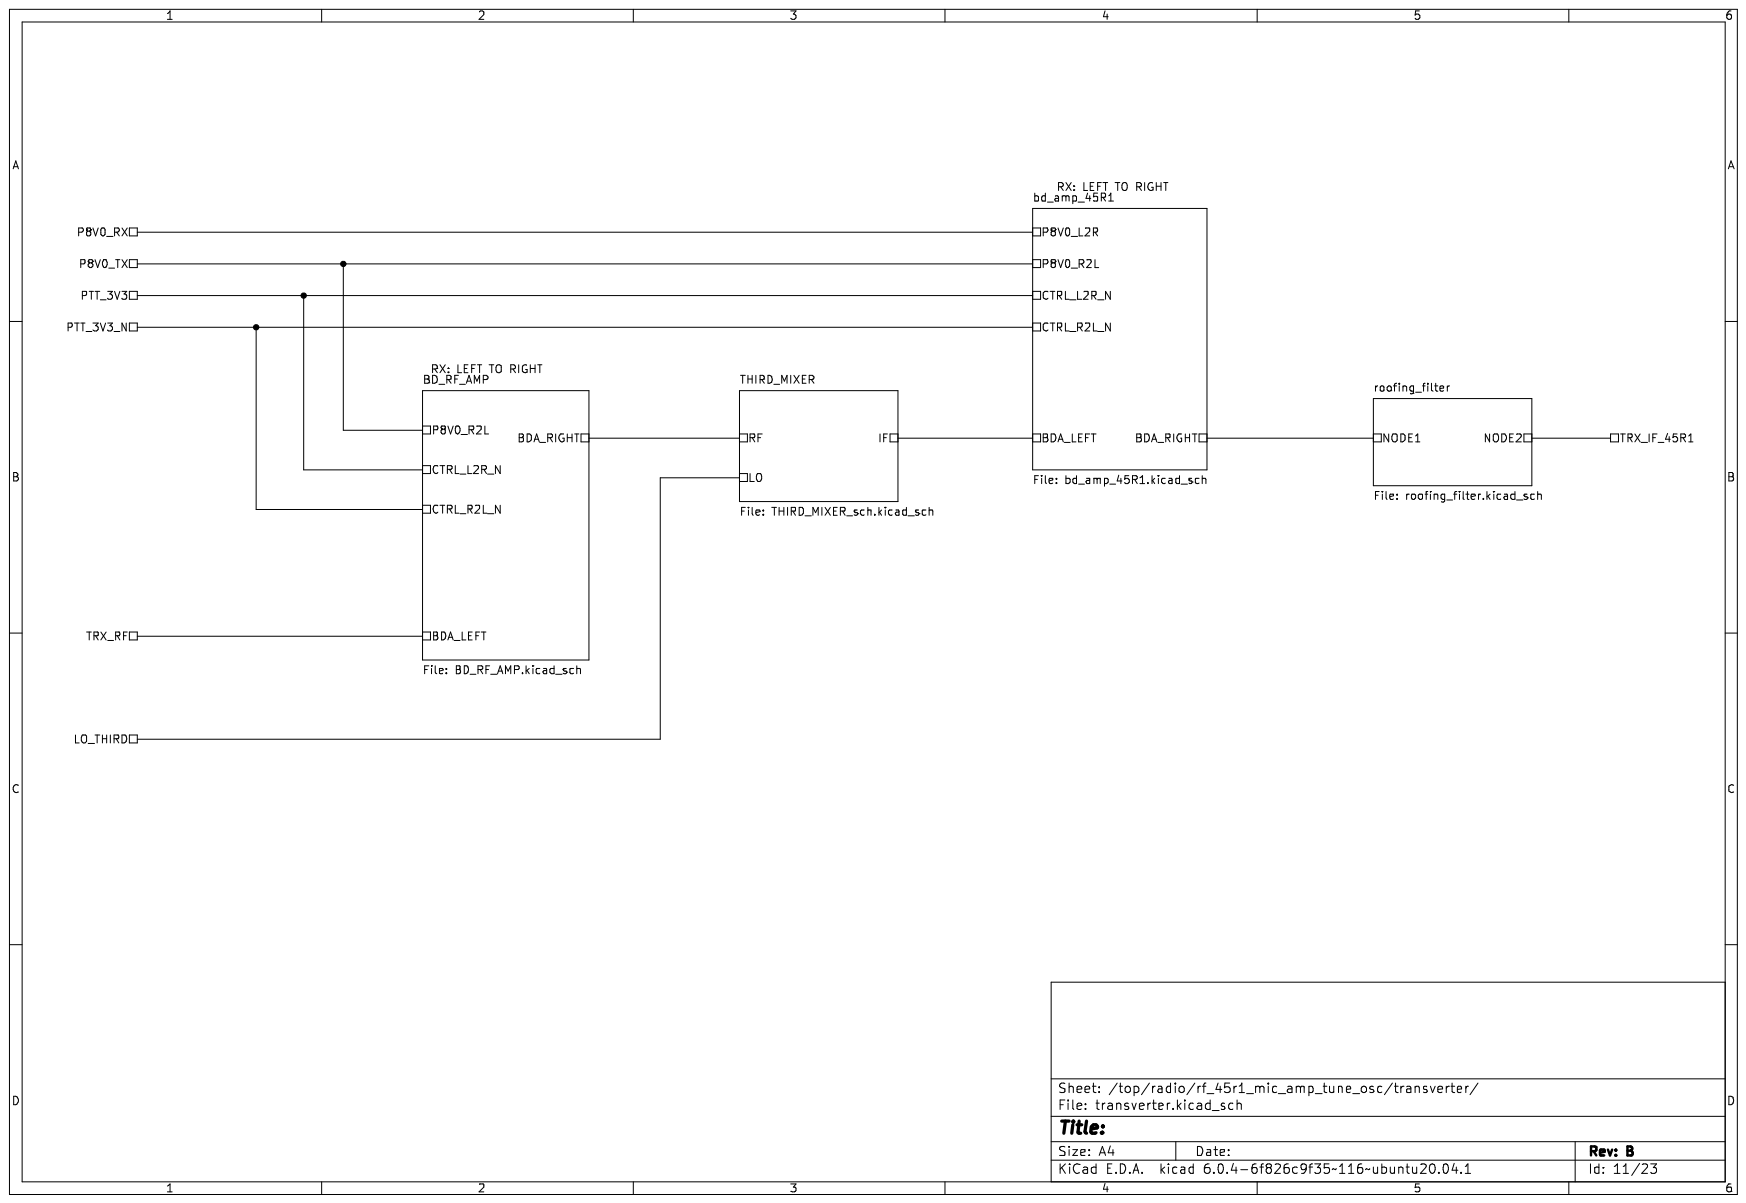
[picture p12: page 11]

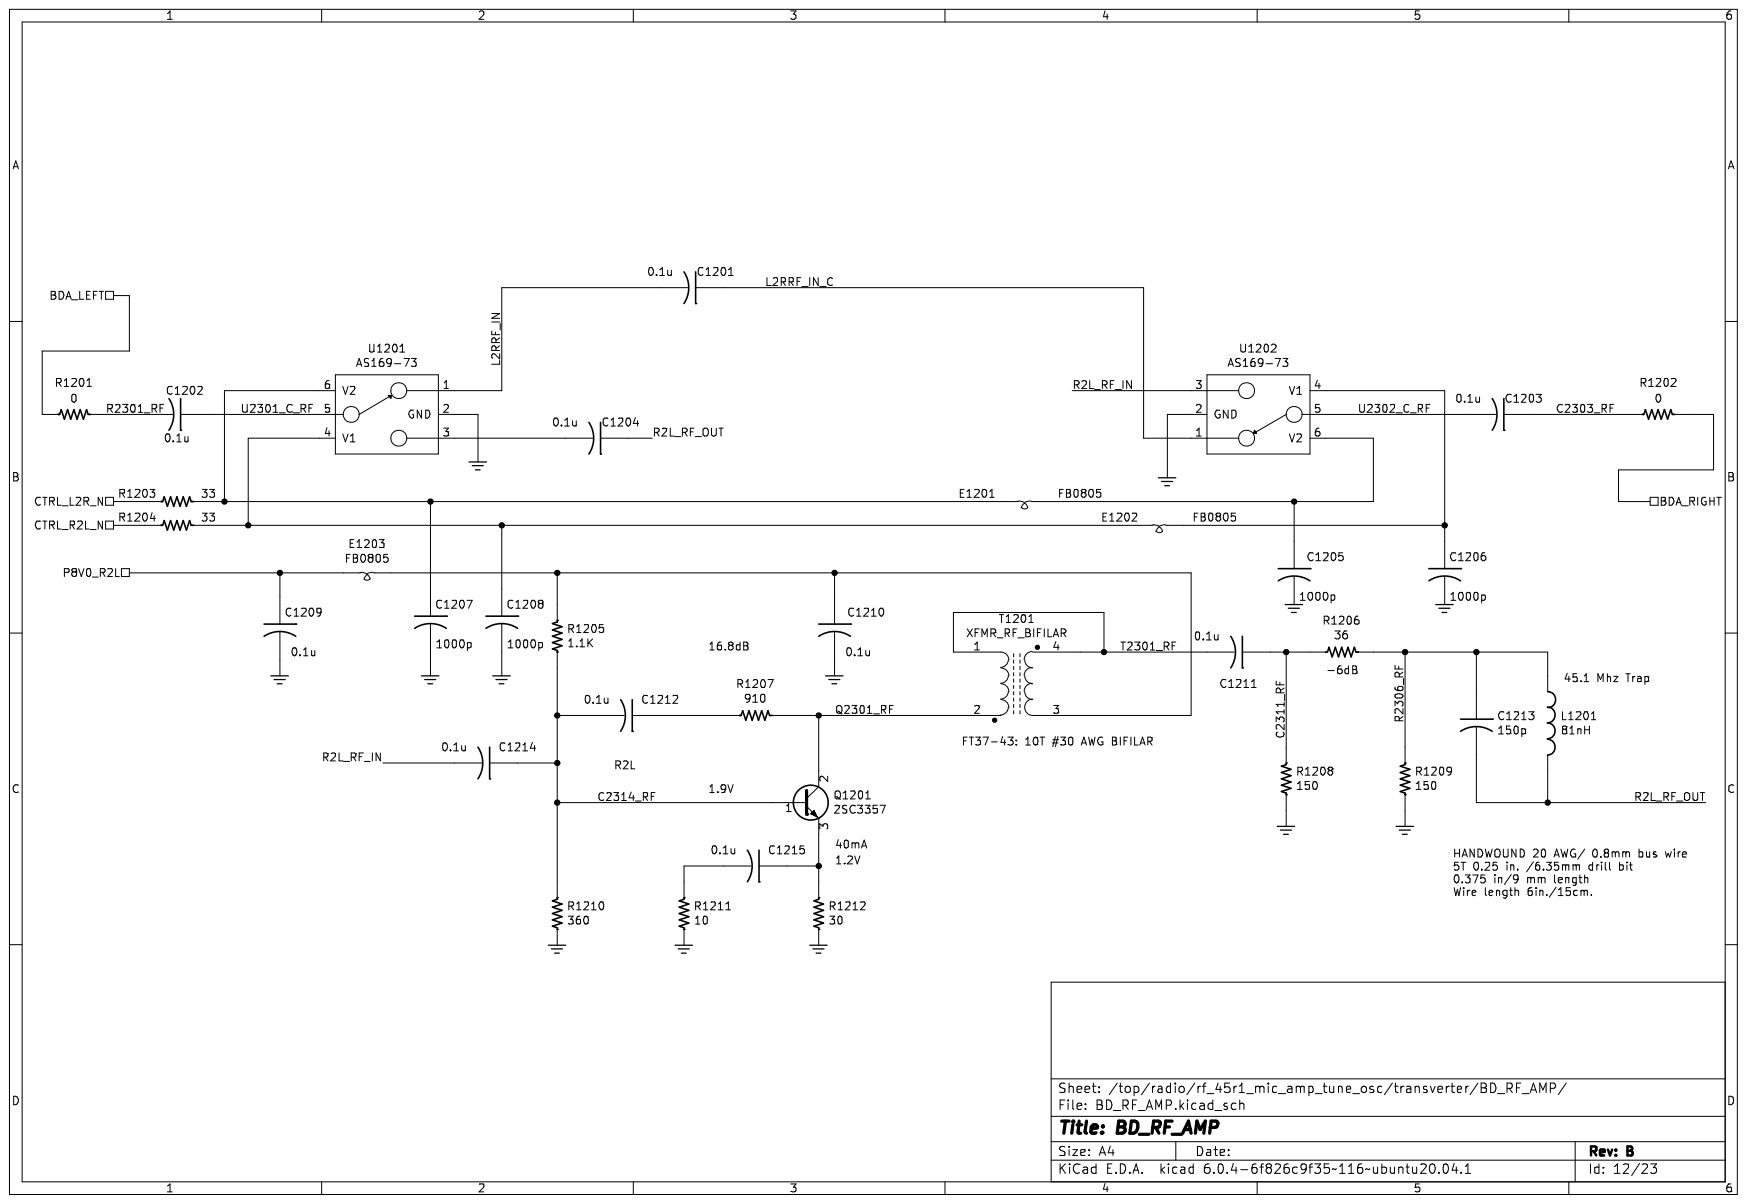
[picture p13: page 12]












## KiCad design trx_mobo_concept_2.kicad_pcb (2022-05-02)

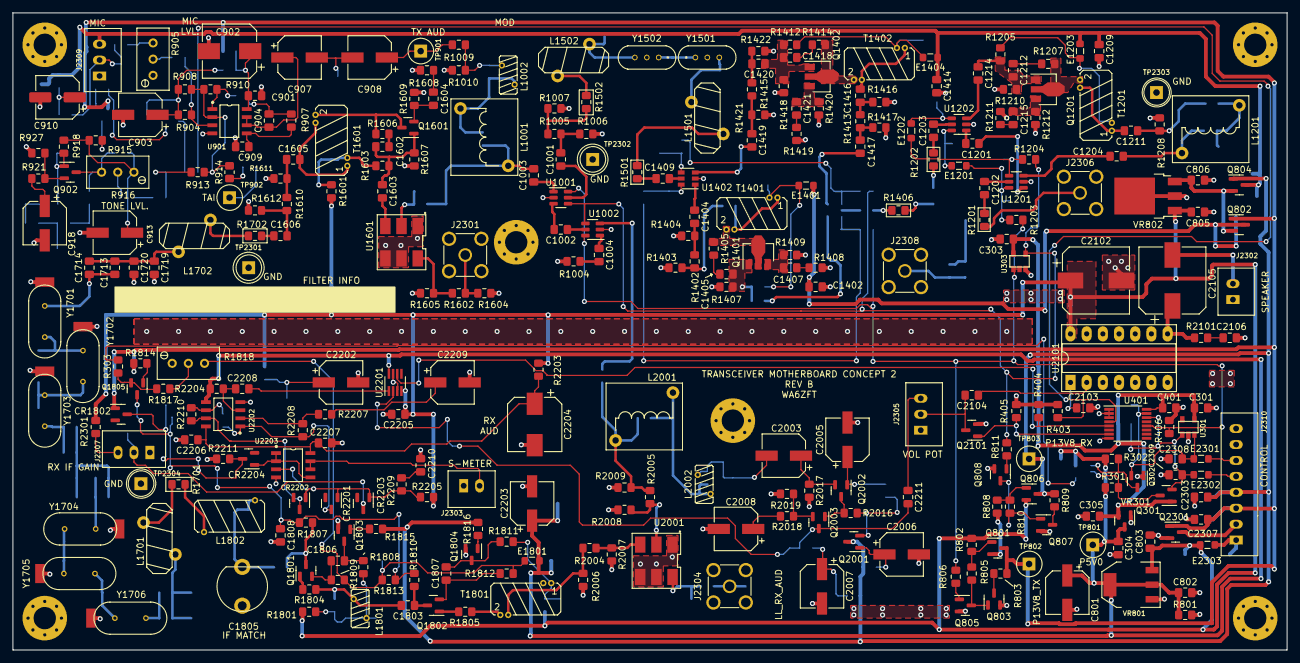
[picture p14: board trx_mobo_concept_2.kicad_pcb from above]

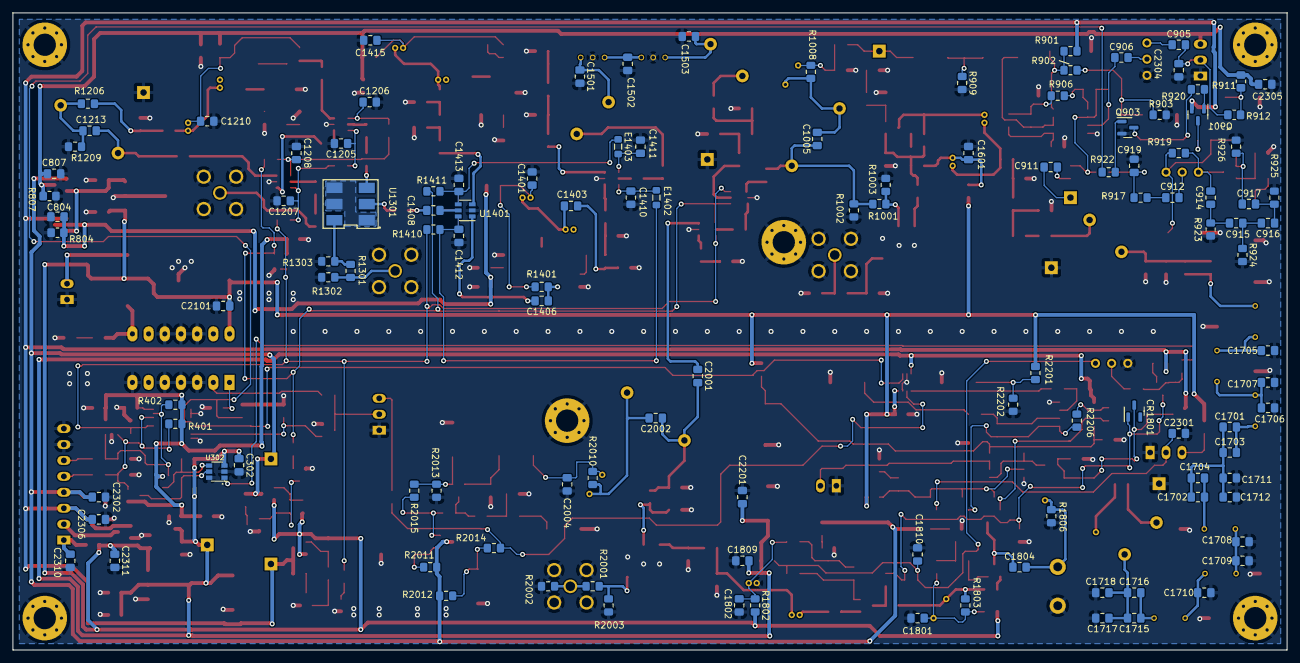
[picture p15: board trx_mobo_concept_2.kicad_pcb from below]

Board: 2 copper layers, 200.0 x 100.0 mm, 422 parts (119 on the bottom side), 226 nets.

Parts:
C301, C302, C303, C401, C802, C804, C807, C901, C905, C906, C911, C912, C1004, C1201, C1202, C1203, C1204, C1209, C1210, C1211, C1212, C1214, C1215, C1601, C1602, C1603, C1604, C1605, C1606, C1801, C1802, C1806, C1807, C1808, C1809, C1810, C2004, C2101, C2106, C2201, C2205, C2206, C2207, C2208, C2301, C2302, C2305, C2306, C2310, C2311: 0.1u; C_0805_2012Metric_Pad1.18x1.45mm_HandSolder
C304, C2210: 1u; C_0805_2012Metric_Pad1.18x1.45mm_HandSolder
C305, C2303, C2307: 10u; C_0805_2012Metric_Pad1.18x1.45mm_HandSolder
C801, C903, C907, C908, C910, C913, C918, C2003, C2005, C2006, C2007, C2008, C2202, C2203, C2209: 22u; CP_Elec_6.3x5.7
C803, C805, C806, C2103, C2104, C2211: 4.7u; C_0805_2012Metric_Pad1.18x1.45mm_HandSolder
C902, C2204: 100u; CP_Elec_8x10
C904, C919, C1001, C1002, C1401, C1402, C1403, C1404, C1405, C1406, C1407, C1408, C1409, C1414, C1415, C1416, C1417, C1418, C1419, C1420, C1421, C1803, C1804: 0.01u; C_0805_2012Metric_Pad1.18x1.45mm_HandSolder
C909, C914, C915, C916, C917: 0.0027u; C_0805_2012Metric_Pad1.18x1.45mm_HandSolder
C1003, C1205, C1206, C1207, C1208, C1410, C1411, C1412, C1413, C2001, C2304: 1000p; C_0805_2012Metric_Pad1.18x1.45mm_HandSolder
C1005, C1213, C1706, C1712, C1713, C1717, C1719, C2002: 150p; C_0805_2012Metric_Pad1.18x1.45mm_HandSolder
C1501, C1503: 16p; C_0805_2012Metric_Pad1.18x1.45mm_HandSolder
C1502: 13p; C_0805_2012Metric_Pad1.18x1.45mm_HandSolder
C1701, C1702: 430p; C_0805_2012Metric_Pad1.18x1.45mm_HandSolder
C1703, C1704: 15p; C_0805_2012Metric_Pad1.18x1.45mm_HandSolder
C1705, C1710: 120p; C_0805_2012Metric_Pad1.18x1.45mm_HandSolder
C1707, C1708, C1714, C1715: 10p; C_0805_2012Metric_Pad1.18x1.45mm_HandSolder
C1709, C1716: 150P; C_0805_2012Metric_Pad1.18x1.45mm_HandSolder
C1711: 18p; C_0805_2012Metric_Pad1.18x1.45mm_HandSolder
C1718, C1720: 20p; C_0805_2012Metric_Pad1.18x1.45mm_HandSolder
C1805: 60p; Cap_Trimmer_THT_6mm_plastic
C2102, C2105: 470u; CP_Elec_10x10
C2308, C2309: 100p; C_0805_2012Metric_Pad1.18x1.45mm_HandSolder
CR1801, CR1802, CR2201, CR2202, CR2203, CR2204: BAT54; SOT23-3-SAR-V2
E1201, E1202, E1203, E1401, E1402, E1403, E1404, E1801, E2301, E2302, E2303: FB0805; L_0805_2012Metric_Pad1.05x1.20mm_HandSolder
J2301, J2304, J2306, J2308: CONN_SMA_VERT; SMA_Kinghelm_KHSMA-KE8-G_Vertical
J2302, J2303: CONN2; JST_B2B_XH_A
J2305, J2307, J2309: CONN3; JST_B3B_XH_A
J2310: CONN8; JST_B8B_XH_A
L1001, L1201, L2001: 81nH; AIR_CORE_9MMX6.3MM
L1002, L1801: 27uH; IND_Handwound_FT23
L1501, L1502: 0.563uH; TOROID_T37_VERT
L1701, L1702: 0.97uH; TOROID_T37_VERT
L1802: 4.13uH; IND_Handwound_FT37
L2002: 15uH; IND_Handwound_FT23
MH2301, MH2302, MH2303, MH2304, MH2305, MH2306: MountingHole_Pad; MountingHole_3.5mm_Pad_Via
Q301, Q302, Q803, Q807, Q1805, Q2101, Q2301: BSS138; SOT-23
Q801, Q802, Q804, Q806: SI2369; SOT-23
Q805, Q808, Q902, Q903, Q1601, Q1803, Q1804, Q2001, Q2002, Q2003: MMBT3904; SOT23-3-SAR-V2
Q901: MMBT3906; SOT23-3-SAR-V2
Q1201, Q1401, Q1402: 2SC3357; SOT-89-3
Q1801, Q1802: MMBFJ310; SOT23-3-SAR-V2
R301, R302, R401, R402, R802, R806, R808, R811, R902, R903, R904, R906, R907, R927, R1815, R1816, R2015, R2201, R2202, R2206, R2207, R2210, R2211, R2301: 10K; R_0805_2012Metric_Pad1.15x1.40mm_HandSolder
R303, R805, R810, R901, R921, R2018, R2203: 100; R_0805_2012Metric_Pad1.15x1.40mm_HandSolder
R403, R404, R405, R406, R915, R1009, R2012, R2014, R2209: 1K; R_0805_2012Metric_Pad1.15x1.40mm_HandSolder
R801: 470; R_0805_2012Metric_Pad1.15x1.40mm_HandSolder
R803, R809, R1211, R1601: 10; R_0805_2012Metric_Pad1.15x1.40mm_HandSolder
R804, R807: 10K; R_0805_2012Metric_Pad1.20x1.40mm_HandSolder
R905, R916, R1818: 20K; Potentiometer_Bourns_3296W_Vertical_Screw_SS
R908: 680; R_0805_2012Metric_Pad1.15x1.40mm_HandSolder
R909: 2K; R_0805_2012Metric_Pad1.15x1.40mm_HandSolder
R910, R1813, R1814: 270K; R_0805_2012Metric_Pad1.15x1.40mm_HandSolder
R911: 100; R_0805_2012Metric_Pad1.20x1.40mm_HandSolder
R912: 6.8K; R_0805_2012Metric_Pad1.20x1.40mm_HandSolder
R913, R2204, R2208: 100K; R_0805_2012Metric_Pad1.15x1.40mm_HandSolder
R914: 100K; R_0805_2012Metric_Pad1.20x1.40mm_HandSolder
R917, R920, R922, R923, R924, R925, R2011: 47K; R_0805_2012Metric_Pad1.15x1.40mm_HandSolder
R918: 75K; R_0805_2012Metric_Pad1.15x1.40mm_HandSolder
R919: 22K; R_0805_2012Metric_Pad1.15x1.40mm_HandSolder
R926, R1807, R1808, R1810, R1811: 39K; R_0805_2012Metric_Pad1.15x1.40mm_HandSolder
R1001, R1005, R1201, R1202, R1406, R1501, R1502, R1701, R1702, R1817: 0; R_0805_2012Metric_Pad1.15x1.40mm_HandSolder
R1002, R1003, R1006, R1007: DNI; R_0805_2012Metric_Pad1.15x1.40mm_HandSolder
R1004, R1010: 51; R_0805_2012Metric_Pad1.15x1.40mm_HandSolder
R1008, R1803, R1806, R2010: 2.2K; R_0805_2012Metric_Pad1.15x1.40mm_HandSolder
R1203, R1204, R1410, R1411: 33; R_0805_2012Metric_Pad1.15x1.40mm_HandSolder
R1205, R1401, R1412: 1.1K; R_0805_2012Metric_Pad1.15x1.40mm_HandSolder
R1206, R1402, R1413, R1415, R1610, R2005: 36; R_0805_2012Metric_Pad1.15x1.40mm_HandSolder
R1207: 910; R_0805_2012Metric_Pad1.15x1.40mm_HandSolder
R1208, R1209, R1403, R1404, R1416, R1417, R1421, R1422, R1611, R1612, R2008, R2009: 150; R_0805_2012Metric_Pad1.15x1.40mm_HandSolder
R1210, R1407, R1418: 360; R_0805_2012Metric_Pad1.15x1.40mm_HandSolder
R1212, R1409, R1420: 30; R_0805_2012Metric_Pad1.15x1.40mm_HandSolder
R1301, R1602, R2001, R2004: 18; R_0805_2012Metric_Pad1.15x1.40mm_HandSolder
R1302, R1303, R1604, R1605, R2002, R2003, R2006, R2007: 300; R_0805_2012Metric_Pad1.15x1.40mm_HandSolder
R1405, R1414, R1606: 1.6K; R_0805_2012Metric_Pad1.15x1.40mm_HandSolder
R1408, R1419, R1608: 6.8; R_0805_2012Metric_Pad1.15x1.40mm_HandSolder
R1603: 8.2K; R_0805_2012Metric_Pad1.15x1.40mm_HandSolder
R1607: 1.5K; R_0805_2012Metric_Pad1.15x1.40mm_HandSolder
R1609: 120; R_0805_2012Metric_Pad1.15x1.40mm_HandSolder
R1801, R1802, R1804, R1805: 82; R_0805_2012Metric_Pad1.15x1.40mm_HandSolder
R1809, R1812: 390; R_0805_2012Metric_Pad1.15x1.40mm_HandSolder
R2013, R2017: 3.3K; R_0805_2012Metric_Pad1.15x1.40mm_HandSolder
R2016: 6.8K; R_0805_2012Metric_Pad1.15x1.40mm_HandSolder
R2019: 4.7K; R_0805_2012Metric_Pad1.15x1.40mm_HandSolder
R2101: 2.7; R_0805_2012Metric_Pad1.15x1.40mm_HandSolder
R2205: 2.2M; R_0805_2012Metric_Pad1.15x1.40mm_HandSolder
T1201, T1401, T1402, T1601: XFMR_RF_BIFILAR; XFMR_Handwound_FT37
T1801: FT37-43; XFMR_Handwound_FT37
TP801, TP802, TP803, TP901, TP902, TP2301, TP2302, TP2303, TP2304: TESTPINTPSQ025; TESTPIN
U301: 24CW640; SOT23-5-SAR
U302: MCP4725; SOT23-6-SAR
U303: 74LVC1G00; SOT23-5-SAR
U401: PCA9554APW; TSSOP-16_4.4x5mm_P0.65mm
U901, U2202, U2203: LMC6482; SOIC8N-SAR
U1001, U1002, U1201, U1202, U1401, U1402: AS169-73; SOT-23-6
U1301, U1601, U2001: ADE-1; MCL-6-SMD_7R97X5R59
U2101: LM380N; DIP-14_W7.62mm_Socket_LongPads
U2201: DG449DS-T1-E3; SOT-23-8_Handsoldering
VR301: ME6211A33M3G-N; SOT23-3-SAR-V2
VR801: NCP1117-5.0_SOT223; SOT-223-TAB-2-SAR
VR802: MC78M08CDTRKG; TO-252-3_TabPin2
Y1501, Y1502: 45.1 MHz; MCF-1.875_7.8x3.2
Y1701, Y1702, Y1703, Y1704, Y1705, Y1706: 12.288 MHz; Crystal_HC49_Vertical_With_Grounding_Pad

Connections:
/top/DIS_AGC_3V3: R404.1, U401.5 (IO1), U2201.6 (IN)
/top/ENA_TUNE_OSC_3V3: R403.1, R922.2, U401.4 (IO0)
/top/IF_GAIN_WIPER: C2301.1, CR2203.3 (C), J2307.2
/top/LO_FIRST: J2301.1, R1602.2, R1604.1
/top/LO_SECOND: J2304.1, R2001.2, R2002.1
/top/P5V0: C302.1, C304.1, C801.1, C802.1, C1809.1, C2201.1, C2203.1, E1801.1, R301.1, R302.1, R801.1, R2204.1, TP801.1 (TP), U302.3 (VDD), U2201.8, U2202.5 (+), VR301.3 (IN), VR801.2 (OUT)
/top/P13V8: C803.1, C805.1, C2101.1, C2102.1, C2205.1, C2311.1, E2303.2, Q801.2 (S), Q806.2 (S), R802.1, R808.1, R1601.2, R1801.2, R1802.2, R2201.2, R2203.2, R2205.2, R2301.1, U2101.14, U2201.4 (V+), VR801.3 (IN), VR802.1 (IN)
/top/P13V8_RX: C2302.1, C2303.1, J2310.4, Q804.1 (G), Q806.3 (D), Q2001.3 (C), R809.1, R1815.2, R1816.2, R2011.1, R2012.1, TP803.1 (TP)
/top/P13V8_TX: C2306.1, C2307.1, CR1802.1 (A), J2310.3, Q801.3 (D), Q802.1 (G), Q901.2 (E), Q2301.1 (G), R803.1, R901.2, R1814.1, TP802.1 (TP)
/top/PTT_3V3: R406.1, R806.2, R1203.2, R1410.2, U303.1, U303.2, U401.12 (IO7), U1001.6 (V2), U1002.6 (V2)
/top/PTT_3V3_N: R811.2, R1204.2, R1411.2, U303.4, U1001.4 (V1), U1002.4 (V1)
/top/RX_AUDIO_SPEAKER: C2105.2, J2302.2
/top/RX_AUDIO_TOP: C2211.1, J2305.3
/top/RX_AUDIO_WIPER: C2104.2, J2305.2, Q2101.3 (D)
/top/SCL_I2C_3V3: C2309.1, E2302.2, Q301.2 (S), R401.2, U301.1 (SCL), U401.14 (SCL)
/top/SDA_I2C_3V3: C2308.1, E2301.2, Q302.2 (S), R402.2, U301.3 (SDA), U401.15 (SDA)
/top/S_METER: J2303.2, U2203.6 (-), U2203.7
/top/TRX_RF: J2306.1, R1201.2
/top/TX_AUDIO_IN: C905.2, C2304.1, J2309.2, R912.1
/top/connectors/LO_THIRD: J2308.1, R1301.2, R1302.1
/top/connectors/P8V0_TX: C807.1, C1209.1, C1414.1, C2305.1, E1203.1, E1404.1, J2309.3, Q804.3 (D), R807.1, R911.2
/top/connectors/SCL_I2C_CONN_3V3: E2302.1, J2310.5
/top/connectors/SDA_I2C_CONN_3V3: E2301.1, J2310.6
/top/connectors/~TX: J2310.2, Q2301.3 (D)
/top/i2c/SCL_I2C_5V0: Q301.3 (D), R301.2, U302.5 (SCL)
/top/i2c/SDA_I2C_5V0: Q302.3 (D), R302.2, U302.4 (SDA)
/top/i2c/TX_IF_GAIN: Q1805.2 (S), R303.1, R1817.2
/top/radio/MUTE_RX_AUDIO: Q2101.1 (G), R405.1, U401.7 (IO3)
/top/radio/ifagc/AGC_IN: CR1801.3 (C), CR1802.3 (C), CR2204.3 (C), R2211.2
/top/radio/ifagc/C903_RF: C1803.1, Q1802.3 (G), R1810.1
/top/radio/ifagc/C904_RF: C1804.1, Q1801.3 (G), R1807.1
/top/radio/ifagc/IF_IN: L1802.2, R1701.2
/top/radio/ifagc/IF_OUT: R2004.2, R2006.1, T1801.4 (S2)
/top/radio/ifagc/L902_RF: C1804.2, C1805.1, L1802.1, R1806.1
/top/radio/ifagc/Q901_RF: Q1801.1 (D), R1804.2
/top/radio/ifagc/Q902_RF: Q1802.1 (D), R1805.2
/top/radio/ifagc/R904_RF: C1803.2, L1801.2, R1803.2, R1804.1
/top/radio/ifagc/R905_RF: R1805.1, T1801.2 (PR2)
/top/radio/mixamp/C805_RF: C1605.1, R1610.2, R1611.1
/top/radio/mixamp/C806_RF: C1606.2, R1610.1, R1612.1
/top/radio/mixamp/IF_OUT_12R288: C1606.1, R1702.1
/top/radio/mixamp/Q801_B_RF: C1602.2, C1603.1, Q1601.1 (B), R1603.2, R1607.1
/top/radio/mixamp/Q810_C_RF: Q1601.3 (C), R1606.1, T1601.2 (PR2)
/top/radio/mixamp/R801_PWR: C1601.1, R1601.1, R1603.1, T1601.3 (S1)
/top/radio/mixamp/RX_IF_IN_45R1: R1001.1, R1003.1, U1601.2 (IF)
/top/radio/mixamp/T801_RF: C1605.2, T1601.1 (PR1), T1601.4 (S2)
/top/radio/mixamp/U801_LO: R1602.1, R1605.1, U1601.6 (LO)
/top/radio/mixamp/U801_RF: C1603.2, U1601.3 (RF)
/top/radio/prod_det_tx_mix/TX_IF_OUT_45R1: C2001.1, U1002.3
/top/radio/prod_det_tx_mix/agc/APBIAS: C2202.1, R2201.1, R2202.2
/top/radio/prod_det_tx_mix/agc/LL_RX_AUDIO: C2211.2, Q2003.3 (C), R2014.2, U2201.2
/top/radio/prod_det_tx_mix/second_mixer_audio_preamp/L1301_RF: C2002.2, L2001.2, L2002.2, R2010.1
/top/radio/prod_det_tx_mix/second_mixer_audio_preamp/R1301_RF: R2001.1, R2003.1, U2001.6 (LO)
/top/radio/prod_det_tx_mix/second_mixer_audio_preamp/R1304_RF: R2004.1, R2007.1, U2001.3 (RF)
/top/radio/prod_det_tx_mix/second_mixer_audio_preamp/R1305_RF: C2001.2, C2002.1, L2001.1, R2005.1, R2009.1
/top/radio/prod_det_tx_mix/second_mixer_audio_preamp/U1301_RF: R2005.2, R2008.1, U2001.2 (IF)
/top/radio/rf_45r1_mic_amp_tune_osc/if_45r1_mic_amp_tune_osc/P8V0_RX: C804.1, C1402.1, E1401.1, Q802.3 (D), R804.1
/top/radio/rf_45r1_mic_amp_tune_osc/if_45r1_mic_amp_tune_osc/TRX_IF_45R1: R1005.1, R1007.1, R1502.1
/top/radio/rf_45r1_mic_amp_tune_osc/if_45r1_mic_amp_tune_osc/speech_amp/AUDIO_O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: C908.1, R1009.2, TP901.1 (TP)
/top/radio/rf_45r1_mic_amp_tune_osc/if_45r1_mic_amp_tune_osc/trx_switch/C1802_RF: C1001.2, R1005.2, R1006.1
/top/radio/rf_45r1_mic_amp_tune_osc/if_45r1_mic_amp_tune_osc/trx_switch/C1805_RF: C1003.2, C1005.1, L1001.1, R1001.2, R1002.1
/top/radio/rf_45r1_mic_amp_tune_osc/if_45r1_mic_amp_tune_osc/trx_switch/L1802_RF: C1005.2, L1001.2, L1002.1, R1008.1
/top/radio/rf_45r1_mic_amp_tune_osc/if_45r1_mic_amp_tune_osc/trx_switch/U1801_C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: C1001.1, U1001.5
/top/radio/rf_45r1_mic_amp_tune_osc/if_45r1_mic_amp_tune_osc/trx_switch/U1801_N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: C1003.1, U1001.1
/top/radio/rf_45r1_mic_amp_tune_osc/if_45r1_mic_amp_tune_osc/trx_switch/U1801_N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: C1002.2, U1001.3
/top/radio/rf_45r1_mic_amp_tune_osc/if_45r1_mic_amp_tune_osc/trx_switch/U1802_C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: C1002.1, U1002.5
/top/radio/rf_45r1_mic_amp_tune_osc/if_45r1_mic_amp_tune_osc/trx_switch/U1802_N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: C1004.1, U1002.1
/top/radio/rf_45r1_mic_amp_tune_osc/transverter/BD_RF_AMP/BDA_RIGHT: R1202.1, U1301.3 (RF)
/top/radio/rf_45r1_mic_amp_tune_osc/transverter/BD_RF_AMP/C2303_RF: C1203.1, R1202.2
/top/radio/rf_45r1_mic_amp_tune_osc/transverter/BD_RF_AMP/C2311_RF: C1211.1, R1206.2, R1208.1
/top/radio/rf_45r1_mic_amp_tune_osc/transverter/BD_RF_AMP/C2314_RF: C1212.2, C1214.1, Q1201.1 (B), R1205.2, R1210.1
/top/radio/rf_45r1_mic_amp_tune_osc/transverter/BD_RF_AMP/L2RRF_IN: C1201.2, U1201.1
/top/radio/rf_45r1_mic_amp_tune_osc/transverter/BD_RF_AMP/L2RRF_IN_C: C1201.1, U1202.1
/top/radio/rf_45r1_mic_amp_tune_osc/transverter/BD_RF_AMP/Q2301_RF: Q1201.2 (C), R1207.1, T1201.2 (PR2)
/top/radio/rf_45r1_mic_amp_tune_osc/transverter/BD_RF_AMP/R2L_RF_IN: C1214.2, U1202.3
/top/radio/rf_45r1_mic_amp_tune_osc/transverter/BD_RF_AMP/R2L_RF_OUT: C1204.1, C1213.2, L1201.2
/top/radio/rf_45r1_mic_amp_tune_osc/transverter/BD_RF_AMP/R2301_RF: C1202.2, R1201.1
/top/radio/rf_45r1_mic_amp_tune_osc/transverter/BD_RF_AMP/R2306_RF: C1213.1, L1201.1, R1206.1, R1209.1
/top/radio/rf_45r1_mic_amp_tune_osc/transverter/BD_RF_AMP/T2301_RF: C1211.2, T1201.1 (PR1), T1201.4 (S2)
/top/radio/rf_45r1_mic_amp_tune_osc/transverter/BD_RF_AMP/U2301_C_RF: C1202.1, U1201.5
/top/radio/rf_45r1_mic_amp_tune_osc/transverter/BD_RF_AMP/U2302_C_RF: C1203.2, U1202.5
/top/radio/rf_45r1_mic_amp_tune_osc/transverter/THIRD_MIXER/IF: R1406.2, U1301.2 (IF)
/top/radio/rf_45r1_mic_amp_tune_osc/transverter/THIRD_MIXER/R2201_RF: R1301.1, R1303.1, U1301.6 (LO)
/top/radio/rf_45r1_mic_amp_tune_osc/transverter/bd_amp_45R1/BDA_RIGHT: C1409.1, R1501.2
/top/radio/rf_45r1_mic_amp_tune_osc/transverter/bd_amp_45R1/C2103_RF: C1403.1, R1402.2, R1403.1
/top/radio/rf_45r1_mic_amp_tune_osc/transverter/bd_amp_45R1/C2104_RF: C1404.1, U1402.1
/top/radio/rf_45r1_mic_amp_tune_osc/transverter/bd_amp_45R1/C2106_RF: C1405.2, C1406.1, Q1401.1 (B), R1401.2, R1407.1
/top/radio/rf_45r1_mic_amp_tune_osc/transverter/bd_amp_45R1/C2108_RF: C1408.1, U1401.5
/top/radio/rf_45r1_mic_amp_tune_osc/transverter/bd_amp_45R1/C2116_RF: C1416.1, R1413.2, R1416.1
/top/radio/rf_45r1_mic_amp_tune_osc/transverter/bd_amp_45R1/C2119_RF: C1419.1, R1415.2, R1421.1
/top/radio/rf_45r1_mic_amp_tune_osc/transverter/bd_amp_45R1/C2120_RF: C1418.2, C1420.1, Q1402.1 (B), R1412.2, R1418.1
/top/radio/rf_45r1_mic_amp_tune_osc/transverter/bd_amp_45R1/L2RRF_IN: C1406.2, U1401.1
/top/radio/rf_45r1_mic_amp_tune_osc/transverter/bd_amp_45R1/Q2101_RF: Q1401.2 (C), R1405.1, T1401.2 (PR2)
/top/radio/rf_45r1_mic_amp_tune_osc/transverter/bd_amp_45R1/Q2102_RF: Q1402.2 (C), R1414.1, T1402.2 (PR2)
/top/radio/rf_45r1_mic_amp_tune_osc/transverter/bd_amp_45R1/R2L_RF_IN: C1419.2, U1402.3
/top/radio/rf_45r1_mic_amp_tune_osc/transverter/bd_amp_45R1/R2L_RF_OUT: C1417.1, U1401.3
/top/radio/rf_45r1_mic_amp_tune_osc/transverter/bd_amp_45R1/R2102_RF: C1404.2, R1402.1, R1404.1
/top/radio/rf_45r1_mic_amp_tune_osc/transverter/bd_amp_45R1/R2106_RF: C1408.2, R1406.1
/top/radio/rf_45r1_mic_amp_tune_osc/transverter/bd_amp_45R1/R2114_RF: C1417.2, R1413.1, R1417.1
/top/radio/rf_45r1_mic_amp_tune_osc/transverter/bd_amp_45R1/R2118_RF: C1420.2, R1415.1, R1422.1
/top/radio/rf_45r1_mic_amp_tune_osc/transverter/bd_amp_45R1/T2101_RF: C1403.2, T1401.1 (PR1), T1401.4 (S2)
/top/radio/rf_45r1_mic_amp_tune_osc/transverter/bd_amp_45R1/T2102_RF: C1416.2, T1402.1 (PR1), T1402.4 (S2)
/top/radio/rf_45r1_mic_amp_tune_osc/transverter/bd_amp_45R1/U2102_RF: C1409.2, U1402.5
/top/radio/rf_45r1_mic_amp_tune_osc/transverter/roofing_filter/L2001_RF: C1501.1, L1501.2, Y1501.1
/top/radio/rf_45r1_mic_amp_tune_osc/transverter/roofing_filter/L2002_RF: L1502.2, R1502.2
/top/radio/rf_45r1_mic_amp_tune_osc/transverter/roofing_filter/R2001_RF: L1501.1, R1501.1
/top/radio/rf_45r1_mic_amp_tune_osc/transverter/roofing_filter/Y2001_RF: C1502.1, Y1501.3, Y1502.3
/top/radio/rf_45r1_mic_amp_tune_osc/transverter/roofing_filter/Y2002_RF: C1503.1, L1502.1, Y1502.1
/top/radio/xtal_filter/C701_RF: C1701.1, C1702.2, C1703.1, C1704.2, C1711.1, C1712.1
/top/radio/xtal_filter/C702_RF: C1702.1, C1704.1, Y1704.1
/top/radio/xtal_filter/C713_RF: C1713.1, C1714.1, Y1701.1
/top/radio/xtal_filter/C715_RF: C1715.2, C1716.2, C1717.1, C1718.1, L1701.2
/top/radio/xtal_filter/C719_RF: C1713.2, C1714.2, C1719.1, C1720.1, L1702.1
/top/radio/xtal_filter/L701_RF: L1701.1, R1701.1
/top/radio/xtal_filter/R702_RF: L1702.2, R1702.2
/top/radio/xtal_filter/Y701_RF: C1705.1, Y1701.3, Y1702.1
/top/radio/xtal_filter/Y702_RF: C1706.1, C1707.1, Y1702.3, Y1703.1
/top/radio/xtal_filter/Y703_RF: C1701.2, C1703.2, Y1703.3
/top/radio/xtal_filter/Y704_RF: C1708.1, C1709.1, Y1704.3, Y1705.1
/top/radio/xtal_filter/Y705_RF: C1710.1, Y1705.3, Y1706.1
/top/radio/xtal_filter/Y706_RF: C1715.1, C1716.1, Y1706.3
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

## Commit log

2022-02-12 Add picture, correct C2002 value in BOM.
    [trx_mobo_concept_2.csv, trx_mobo_concept_2_smt_bottom.csv, trx_mobo_concept_2_smt_top.csv]
2022-02-23 Change to KiCAD 6
    [BD_RF_AMP.kicad_sch, BD_RF_AMP.sch, I2C_Expander.kicad_sch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]
2022-02-23 Update pcb database to version 6
    [BD_RF_AMP.kicad_sch, I2C_Expander.kicad_sch, THIRD_MIXER_sch.kicad_sch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]
2022-02-24 Sync PCB with schematic
    [bd_amp_45R1.kicad_sch, control.kicad_sch, i2c.kicad_sch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]
2022-02-27 Fix BOM part number errors and out of sync footprints which happened during conversion from Kicad 5 to 6
    [BD_RF_AMP.kicad_sch, I2C_Expander.kicad_sch, THIRD_MIXER_sch.kicad_sch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]
2022-02-27 Fix missing part number for 330 ohm resistor
    [trx_mobo_concept_2.csv, trx_mobo_concept_2_smt_top.csv]
2022-02-27 Fix incorrect part number for 470uf capacitor
    [audio_amp.kicad_sch, trx_mobo_concept_2.csv, trx_mobo_concept_2_smt_top.csv]
2022-02-28 Fix R917 silkscreen
    [trx_mobo_concept_2.kicad_pcb]
2022-03-10 Change bias resistors on 2SC3357 amplifiers to stay under 12V across Vbe.
    [BD_RF_AMP.kicad_sch, bd_amp_45R1.kicad_sch, trx_mobo_concept_2.csv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]
2022-05-02 trx_mobo_concept_2_B. Change design to use a dedicated 8V supply for the 2SC3357 parts. Add S-Meter connector. Change mic connector to 3 pins and add 8V sopower supply to pin 3.
    [BD_RF_AMP.kicad_sch, I2C_Expander.kicad_sch, THIRD_MIXER_sch.kicad_sch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]
2022-05-02 Fix 12.288MHz part number in schematic, regenerate BOM's.
    [connectors.kicad_sch, ifagc.kicad_sch, speech_amp.kicad_sch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]
